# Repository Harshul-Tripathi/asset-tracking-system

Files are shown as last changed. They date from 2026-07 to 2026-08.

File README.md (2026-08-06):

# Anti-Theft Tracking

An industrial project developed in collaboration with **STMicroelectronics** to design and implement a highly accurate, multi-anchor asset tracking and anti-theft system utilizing Ultra-Wideband (UWB) technology that offers centimeter-level precision. 

This repository contains the complete firmware, hardware PCB designs, and comprehensive documentation for the entire project lifecycle.

---
## 👥 Contributors

*   Krishang Singh - Hardware selection, Schematic and Layout design, Low-power optimization
*   Krishna Kumar Mahto - Firmware, Qorvo SDK, Breadboard testing (one way ranging)
*   Harshul Tripathi - MCU Pinout Architecture (CubeMX), AirTag Analysis, System Power Profiling

## 🏗️ System Architecture

The tracking ecosystem relies on a 4-subsystem architecture designed for precise trilateration and efficient power management. The system consists of three stationary anchors and one mobile tag:

### 1. STM32 Anchor (Hub)
*   **Hardware:** NUCLEO-U575ZI-Q + BU03 (UWB Module) + ST67W611M (Wi-Fi Module)
*   **Role:** Acts as the central hub of the tracking system. It interfaces with the tag and the secondary ESP32 anchors to compute the final location of the asset and manage the network. It publishes this data to a dashboard through the ST67W611M Wi-Fi module.
*   **Location:** `firmware/stm32-anchor-hub/nucleo-u575zi-q_bu03/`

### 2. ESP32 Anchors (x2)
*   **Hardware:** ESP32 + UWB Modules
*   **Role:** Two secondary stationary anchors strategically placed to provide the additional reference points required for accurate 2D/3D trilateration. 
*   **Location:** `firmware/esp32-anchors/`

### 3. STM32 Tag
*   **Hardware:** NUCLEO-WBA55CG + BU03 (UWB Module) / Custom Compact PCB
*   **Role:** The mobile asset being tracked. Designed for a compact footprint, it broadcasts its signals to the anchor network.
*   **Location:** `firmware/stm32-tag/Nucleo-WBA55CG_BU03/`

---

## 📂 Repository Structure

The repository is modularized to separate different microcontrollers, hardware designs, and documentation, preventing workspace conflicts.

*   **`/docs`**: Contains all reference materials, component datasheets, project presentations, and research (including AirTag teardowns).
*   **`/firmware`**: Separated source code for the ESP-IDF and STM32CubeIDE workspaces. Each subsystem contains its own build instructions and configurations.
*   **`/hardware`**: Contains the custom compact tag PCB designs (KiCad/Altium). Includes standard EDA source files alongside a `/production` folder for manufacturing Gerbers and BOMs.
  ---

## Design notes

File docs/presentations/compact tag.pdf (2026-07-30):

# Compact Tag w/ STM32WBA55

# -Battery Life Optimization -Communication Modes -Productization Plan

## Current System schematic

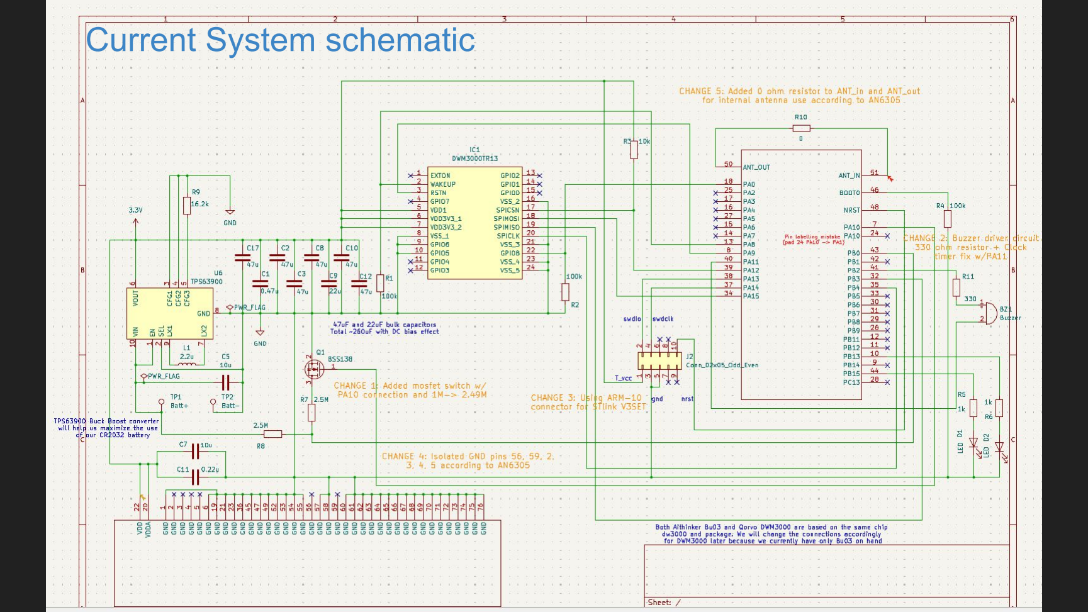
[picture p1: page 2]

# DWM3000 + MLCC Ideal Parameters & Lifespan

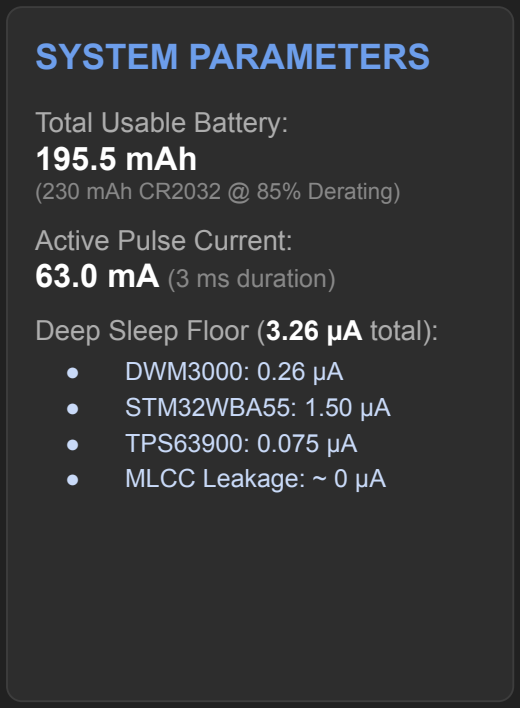
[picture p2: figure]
SYSTEM PARAMETERS; Total Usable Battery: 195.5 mAh; (230 mAh CR2032 @ 85% Derating); Active Pulse Current: 63.0 mA (3 ms duration); Deep Sleep Floor (3.26 µA total):; ● DWM3000: 0.26 µA ● STM32WBA55: 1.50 µA; ● TPS63900: 0.075 µA; ● MLCC Leakage: ~ 0 µA

SCENARIO A: 1 HZ

1 Pulse per Second (86,400/Day)

Active Drain / Day:
3.841 mAh

Sleep Drain / Day:
0.163 mAh

Total Daily Drain:
4.004 mAh/day

ESTIMATED LIFESPAN

# ~48.8 Days

SCENARIO B: 3 HZ

3 Pulses per Second (259,200/Day)

Active Drain / Day:
11.524 mAh

Sleep Drain / Day:
0.162 mAh

Total Daily Drain:
11.686 mAh/day

ESTIMATED LIFESPAN

# ~16.7 Days

# Full tag system Realistic Parameters & Lifespan

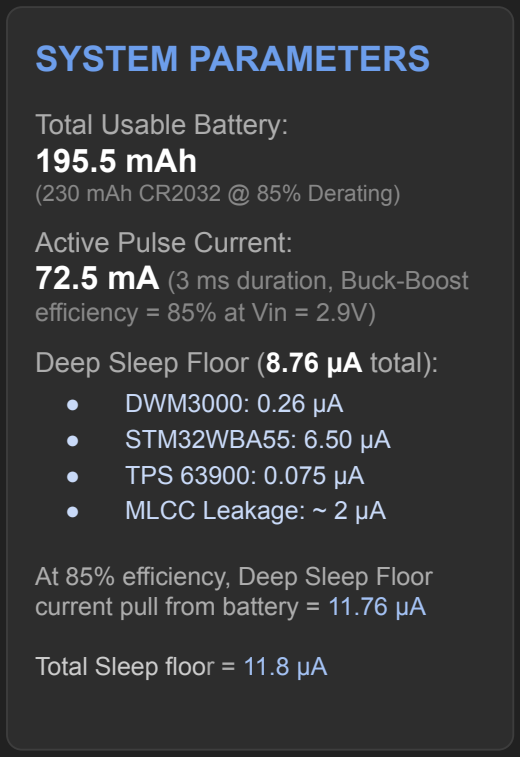
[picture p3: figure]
SYSTEM PARAMETERS; Total Usable Battery: 195.5 mAh; (230 mAh CR2032 @ 85% Derating); Active Pulse Current: 72.5 mA (3 ms duration, Buck-Boost; efficiency = 85% at Vin = 2.9V); Deep Sleep Floor (8.76 µA total):; ● DWM3000: 0.26 µA ● STM32WBA55: 6.50 µA; ● TPS 63900: 0.075 µA ● MLCC Leakage: ~ 2 µA; At 85% efficiency, Deep Sleep Floor current pull from battery = 11.76 µA; Total Sleep floor = 11.8 µA

SCENARIO A: 1 HZ

1 Pulse per Second (86,400/Day)

Active Drain / Day:
5.220 mAh

Sleep Drain / Day:
0.282 mAh

Total Daily Drain:
5.502 mAh/day

ESTIMATED LIFESPAN

# ~35.5 Days

Assuming UWB usage

### 15 mins/ week

# ~13.5 Months

SCENARIO B: 3 HZ

3 Pulses per Second (259,200/Day)

Active Drain / Day:
15.660 mAh

Sleep Drain / Day:
0.281 mAh

Total Daily Drain:
15.941 mAh/day

ESTIMATED LIFESPAN

# ~12.3 Days

Assuming UWB usage

### 15 mins/ week

# ~13 Months

# Apple Airtag Power delivery inspiration

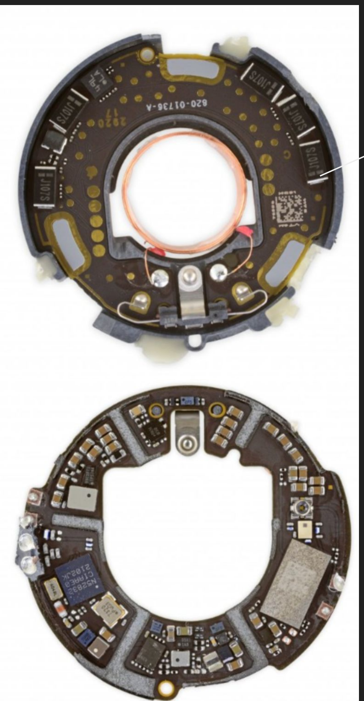
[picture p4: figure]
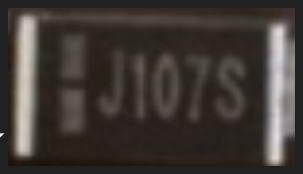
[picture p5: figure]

Capacitance rating (107) : 100 UF Voltage Rating (J) : 6.3V
Tolerance (S) : +50% , -20%
Type : Polymer Tantalum

We can see 5 of these so net total capacitance is around 500 uF

Our system uses following Bulk MLCCs:
6 x 47uF(25V) = 282uF
1 x 22uF(25V) = 22uF
Net Bulk capacitance = 304uF

## The usage of MLCCs allows for no leakage

capacitance and gives us a better UWB lifespan.

# Major Changes Needed for Productization

### Change 1: Integration with BLE(Bluetooth Low Energy) technology

- We utilize the UWB module with another BLE setup (like the one we saw in our visit or
BlueNRG-M2 or STM32WBA5MMG+ANT3216A063R2400A)
- We can use the BLE setup 99% (UWB deep sleep, 142 nA) of the time to conserve battery and get to proximity of the tag without bothering with UWB unless we get close to the tag (<20m) .

### Change 2: Double-Sided Two-Way Ranging (DS-TWR) for UWB communication

Changing our older single-sided ranging system for DS-TWR:

- Stage-1 (Tag Tx , Anchor Rx)- Tag transmits signal for the
initiation of the distance + direction measurement.
- Stage-2 (Tag Rx , Anchor Tx)- Anchor transmits a signal and
also starts counter for ToF then tag receives.
- Stage-3 (Tag Tx , Anchor Rx)- Tag transmits signal while the

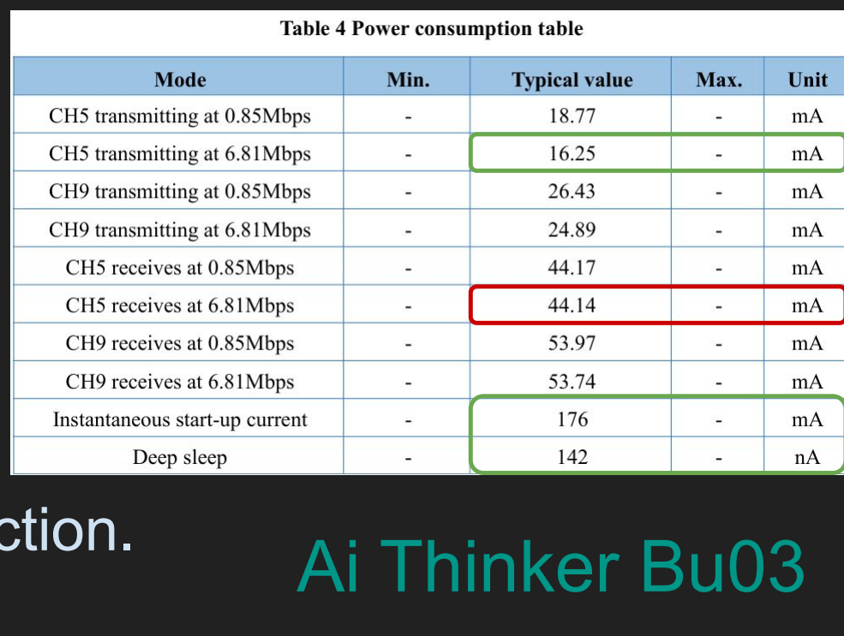
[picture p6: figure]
Ai Thinker Bu03

Anchor receives and stops ToF counter , to find distance + direction.

https://www.st.com/en/wireless-connectivity/bluenrg-m2.html (https://www.st.com/en/wireless-connectivity/bluenrg-m2.html) https://www.digikey.in/en/products/detail/yageo/ANT3216A063R2400A/311-1542-1-ND/3927225 (https://www.digikey.in/en/products/detail/yageo/ANT3216A063R2400A/311-1542-1-ND/3927225)

# Change-1 detailed

- For most of the battery life ,our UWB subsystem will be virtually nonexistent and we will only use BLE technology with Find My app (on iOS w/ UWB support) or Find My Device(by Google,No UWB support).
- Our Tag BLE subsystem will act like a beacon that will broadcast its ID every 2s to every nearby device in its own ecosystem (say iOS) .
- The device will have a GPS location that will upload the Tag ID to Apple cloud which will get picked up by our own Anchor (iPhone) that will give us a rough location as to where our tag is.

~20m

BLE
only

UWB+
minimal
BLE

Anchor(iPhone)

Tag

- Once we get to a reasonable proximity (about 20m), our BLE subsystem will
start using its RSSI indicator to find rough distance between the tag and anchor (accuracy in meters) and when the strength is adequate (around -65 dBm), our MCU will get our UWB subsystem out of Deep-Sleep and into active mode.
- Then we can use our iPhone (with U2/U1 chip) to track the direction and distance to our

DW3000 chip based UWB module/setup without our Change-2 tracking method. Qorvo Nearby Interaction or Apple’s Find My app can handle this part well.

RSSI
starts

# Getting Access to Apple’s Find My

## Apple allows third party devices to enter their iOS ecosystem if they comply with certain guidelines* using the MFi program and have suitable BLE technology in

your circuit.

## A temporary work-around we can use is a masked ID to utilize Apple’s Find My network for BLE purposes and

Qorvo’s nearby interaction for UWB tracking.

## Dw3000 based modules that we plan to use are compliant with IEEE 802.15.4z standard of UWB communication which is also found in UWB subsystems

of higher-end android phones.

*

https://mfi.ap
ple.com/en/h
ow-it-works.ht
ml (https://mfi.apple.com/en/enroll.html)
Portronics World Tag

https://github.com/see
moo-lab/openhaystack (https://github.com/seemoo-lab/openhaystack)

The industry standard method to use UWB communication in unknown terrain is DS-TWR in which we have a 3-signal broadcast (Initialise, Anchor return and Tag return in order)

### 1. Initialize : Tag in Tx mode sends a signal to Anchor to basically

inform the anchor that the tag is reachable for distance calculation, just like t_ready signal sent by slave in AXI.

### 2. Anchor return : Anchor sends the starter signal for

ToF calculation and gets into Rx mode for the Tag return signal.

### 3. Tag return : Tag sends the signal back to anchor to

end the ToF on anchor side and our iPhone anchor is capable of finding the distance and direction from the ToF alone.

# Change-2 detailed

### Anchor

## Tag

Initialise Tag
return

Anchor
return

## TAG

# DS-TWR current pull pattern

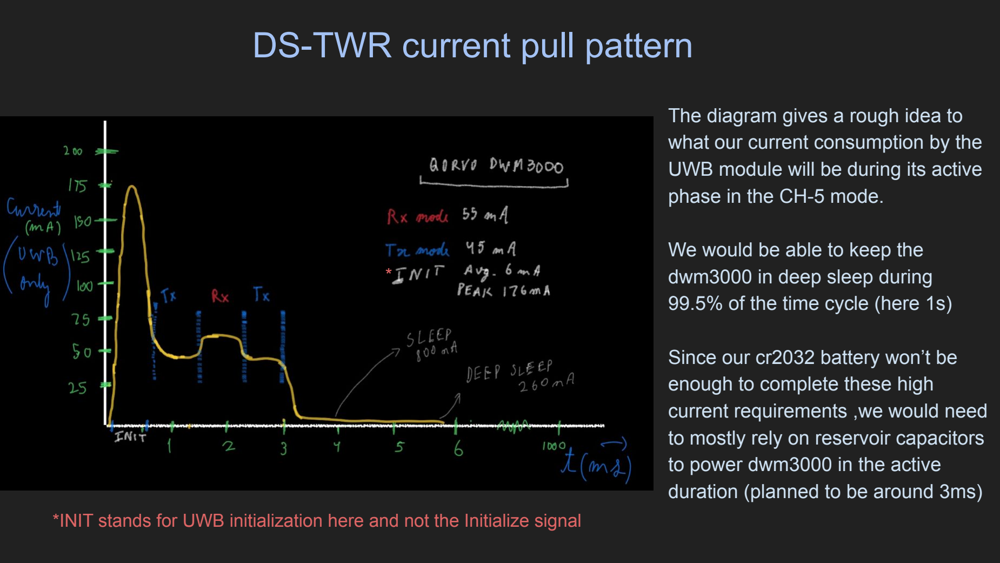
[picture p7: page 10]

The diagram gives a rough idea to what our current consumption by the UWB module will be during its active phase in the CH-5 mode.

We would be able to keep the dwm3000 in deep sleep during 99.5% of the time cycle (here 1s)

Since our cr2032 battery won’t be enough to complete these high current requirements ,we would need to mostly rely on reservoir capacitors to power dwm3000 in the active duration (planned to be around 3ms)

*INIT stands for UWB initialization here and not the Initialize signal

*

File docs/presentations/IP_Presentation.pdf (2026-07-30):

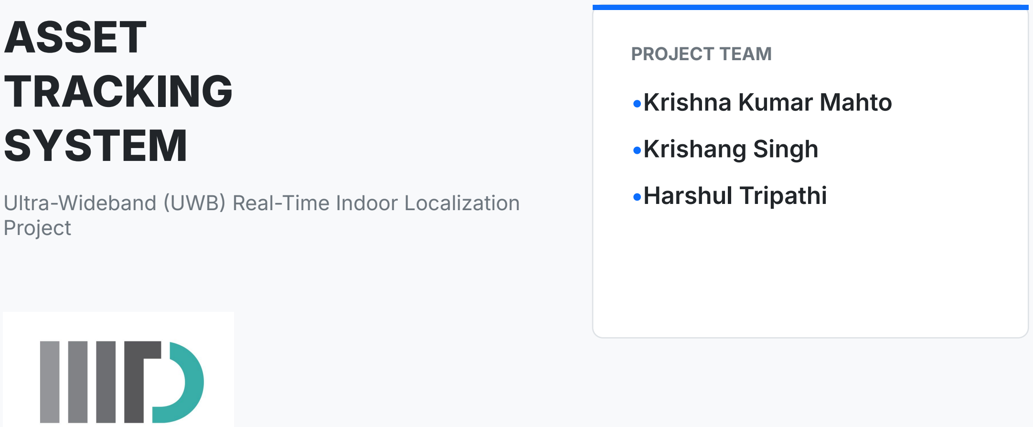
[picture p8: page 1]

# ASSET TRACKING SYSTEM

Ultra-Wideband UWB Real-Time Indoor Localization Project

PROJECT TEAM

### •Krishna Kumar Mahto

### •Krishang Singh

### •Harshul Tripathi

# System Architecture: UWB Tag & Anchor

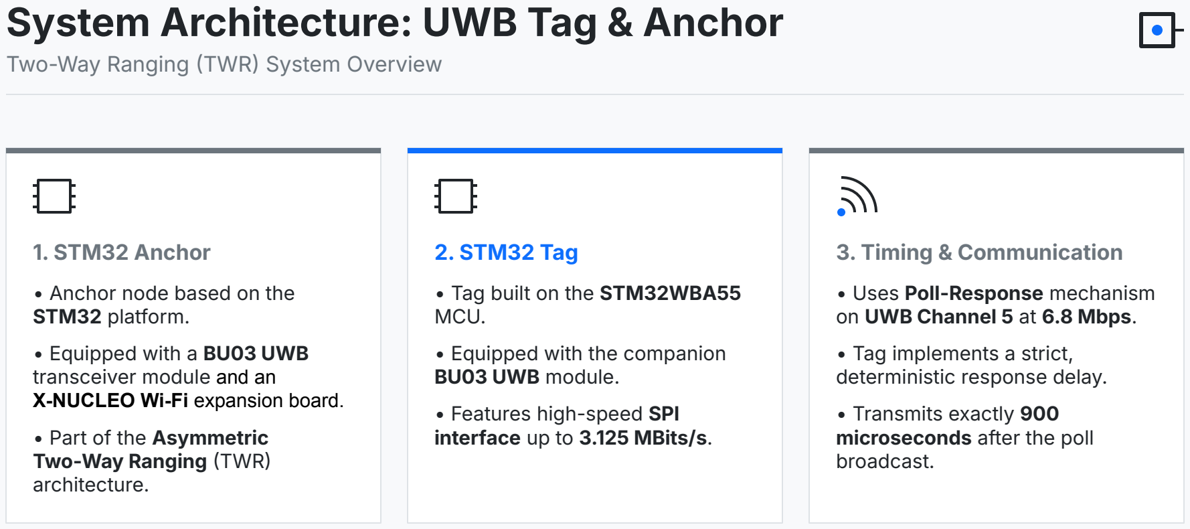
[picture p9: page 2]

Two-Way Ranging TWR System Overview

### 1. STM32 Anchor

- Anchor node based on the STM32 platform.
- Equipped with a BU03 UWB transceiver module and an
X-NUCLEO Wi-Fi expansion board.
- Part of the Asymmetric
Two-Way Ranging TWR
architecture.

### 2. STM32 Tag

- Tag built on the STM32WBA55 MCU.
- Equipped with the companion BU03 UWB module.
- Features high-speed SPI
interface up to 3.125 MBits/s.

### 3. Timing & Communication

- Uses Poll-Response mechanism on UWB Channel 5 at 6.8 Mbps.
- Tag implements a strict, deterministic response delay.
- Transmits exactly 900
microseconds after the poll broadcast.

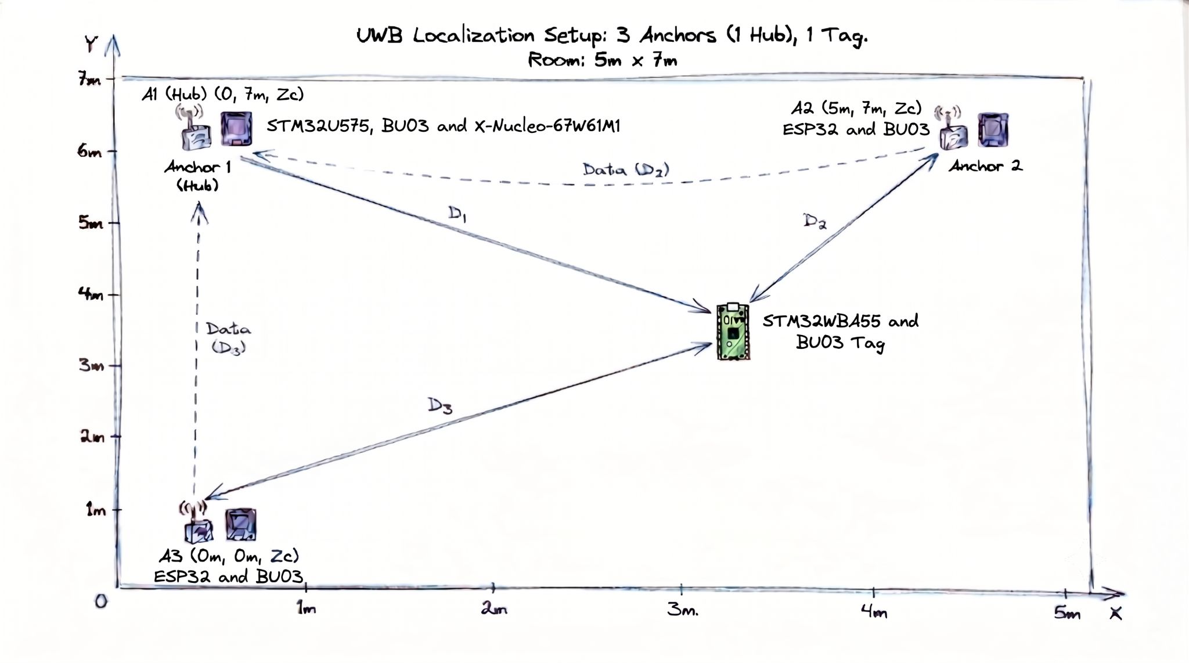
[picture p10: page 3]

# Hardware Specifications

Tag, Anchor, and BU03 Transceiver profiles

TAG NODE HARDWARE

System Platform
STMicroelectronics NUCLEOWBA55CG

MCU: STM32WBA55CGUx
CORE: Cortex-M33 @ 100MHz
OS: Baremetal (No RTOS)
Custom baremetal firmware guarantees nanosecond-level timing precision by eliminating scheduling overhead.

ANCHOR & TRANSCEIVER

Anchor Processing Unit
BOARD: NUCLEO-U575ZI-Q
CORE: STM32U575

Wi-Fi Expansion Profile
BOARD:X-NUCLEO-67W61M1
INTERFACE: Shared SPI1 (via Arduino Uno V3 headers)
Shared UWB Transceiver Profile
MODULE: BU03 Module
TRANSCEIVER: Qorvo / Decawave DW3000 PHY CH / RATE: Channel 5 @ 6.8 Mbps PREAMBLE: 128 Length

# Tag Interfacing & Wiring

STM32WBA BU03

PA15 | MOSI Data Out)
PB3 | MISO Data In)
PB4 | SCK Serial Clock
SPI1 Interface | Control & Debug
PA12 | CS Chip Select
Active Low)
PA11 | RST Hardware Reset)
PB14 | IRQ EXIT 14 Notification)
UART1 | TXPB12 RXPA8

### CRITICAL CONFIGURATION Real-time RX/TX event notifications are handled via the EXTI14

interrupt line on PB14. The debug console operates over UART1 at 115200 baud.

# Anchor Hub Interfacing & Wiring

STM32U5 BU03 & XNUCLEO67W61M1

PB15 | MOSI Data Out)
PB14 | MISO Data In)
PB13 | SCK Serial Clock
SPI2 Interface : BU03 and STM32U5 | Control & Debug
PA4 | CS Chip Select
Active Low)
PB2 | RST Hardware Reset)
PF12 | IRQ EXIT14 Notification)
PF11 | WAKE

### ❖ We are stacking the XNUCLEO67W61M1 Wi-Fi expansion board directly onto the

STM32 Nucleoʼs Arduino Uno V3 connectors to establish a multi-slave SPI1 bus layout.

# Execution Trace & Validation

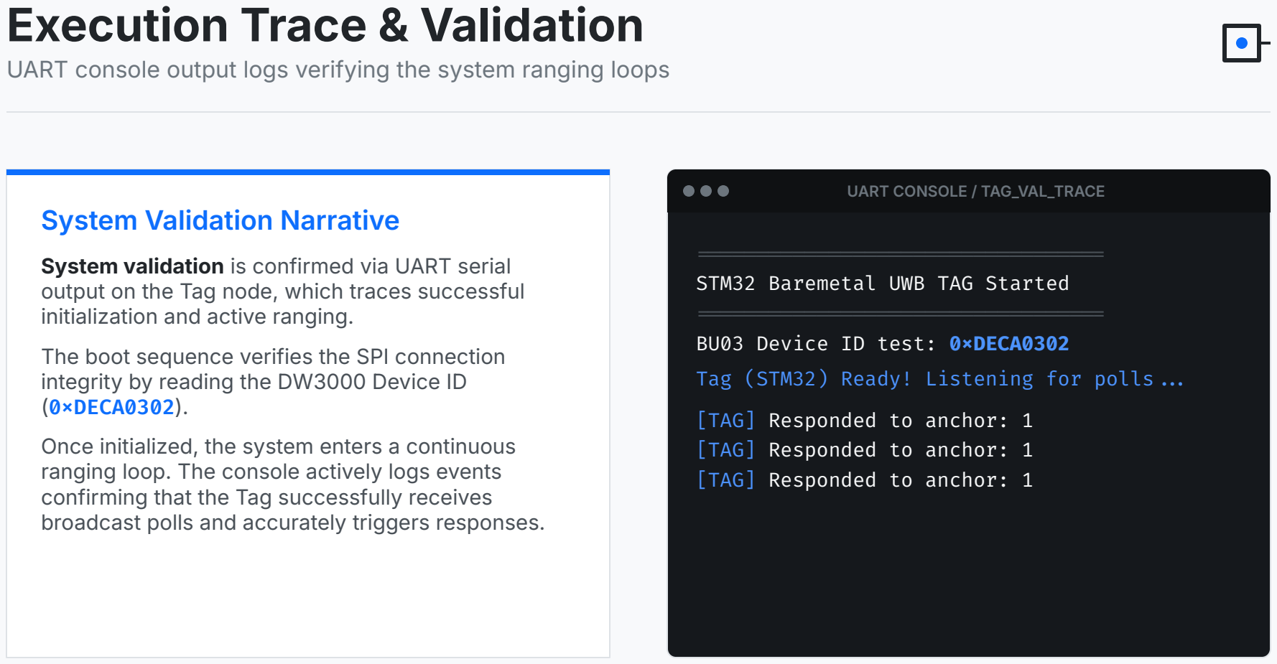
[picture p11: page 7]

UART console output logs verifying the system ranging loops

### System Validation Narrative

System validation is confirmed via UART serial output on the Tag node, which traces successful initialization and active ranging.
The boot sequence verifies the SPI connection integrity by reading the DW3000 Device ID (0xDECA0302).
Once initialized, the system enters a continuous ranging loop. The console actively logs events confirming that the Tag successfully receives broadcast polls and accurately triggers responses.

UART CONSOLE / TAG_VAL_TRACE

================================== STM32 Baremetal UWB TAG Started ==================================
BU03 Device ID test: 0xDECA0302
Tag (STM32) Ready! Listening for polls... [TAG] Responded to anchor: 1
[TAG] Responded to anchor: 1
[TAG] Responded to anchor: 1

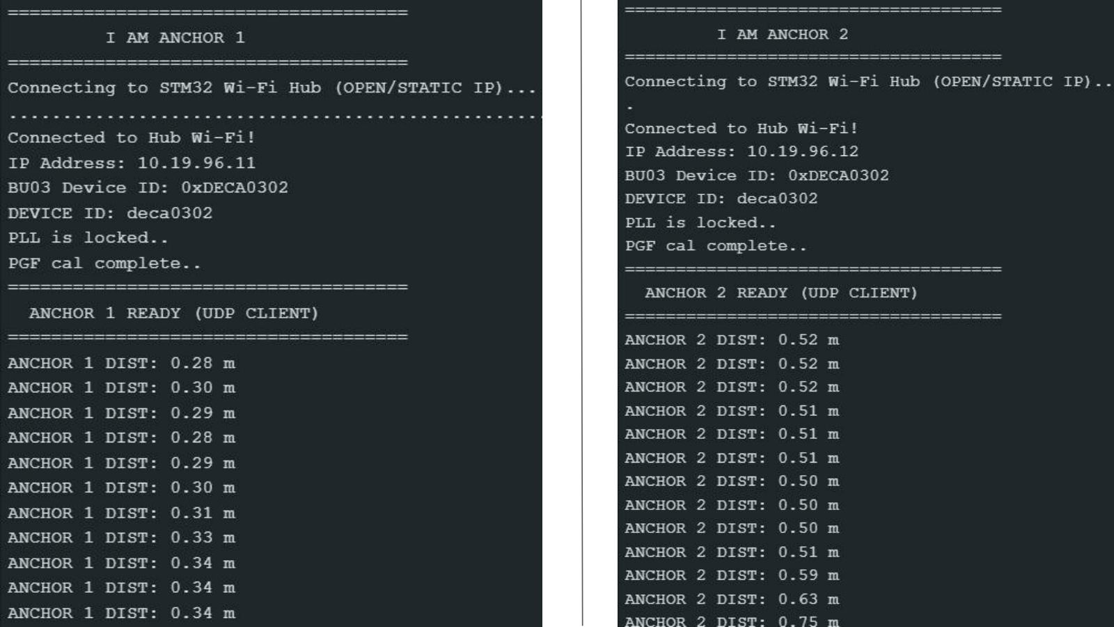
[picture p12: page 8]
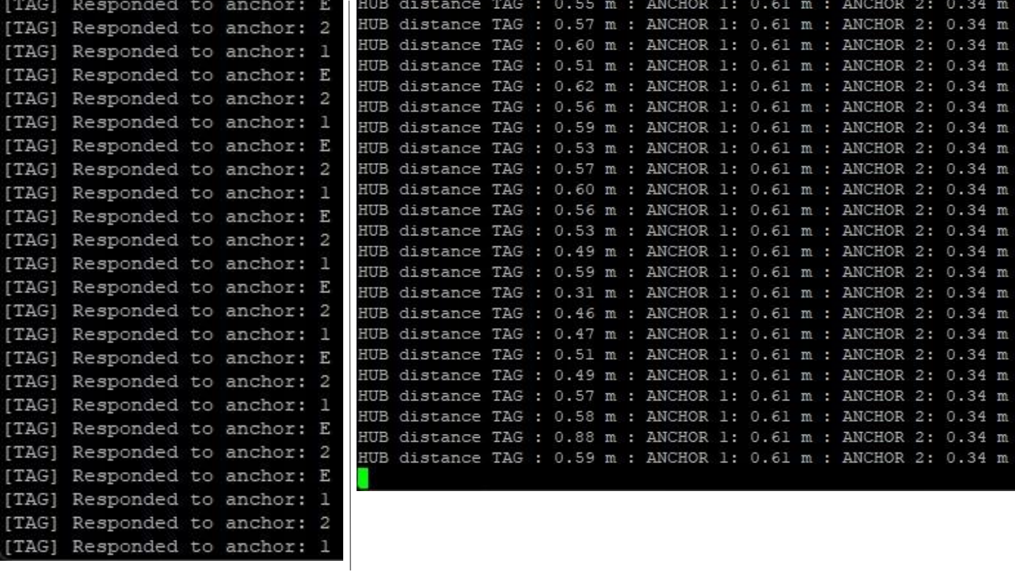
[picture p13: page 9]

### Web-Dashboard

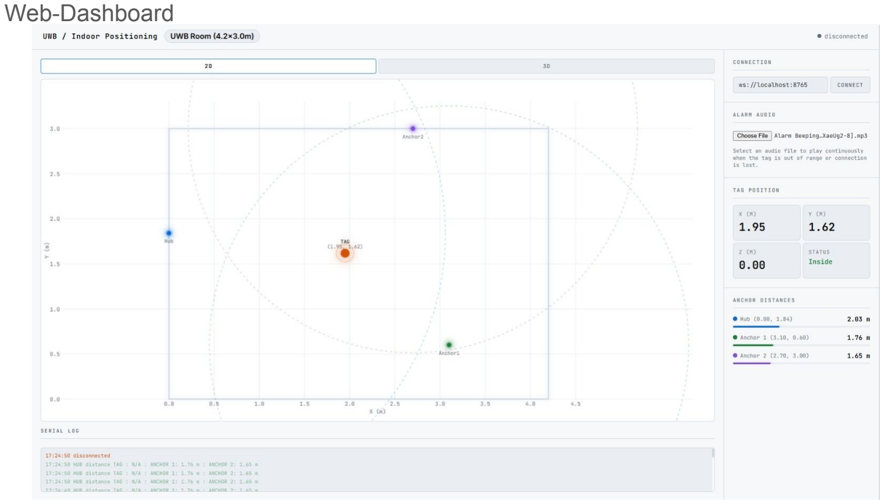
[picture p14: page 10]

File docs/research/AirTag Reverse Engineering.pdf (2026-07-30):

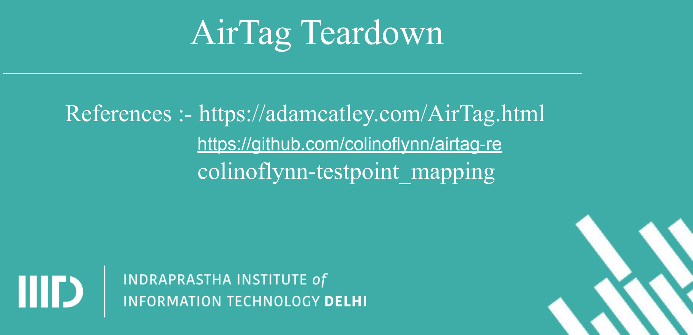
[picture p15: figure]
AirTag Teardown; colinoflynn-testpoint_mapping

# References :- https://adamcatley.com/AirTag.html

# https://github.com/colinoflynn/airtag-re

# Teardown

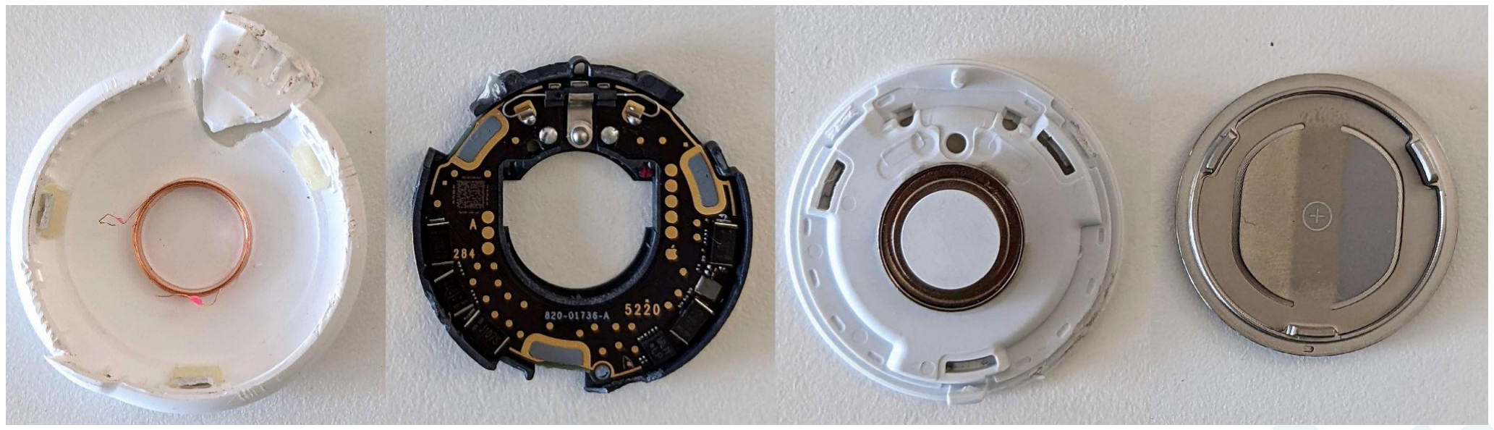
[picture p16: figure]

# Key Findings

### Hardware & Power

- Uses off the shelf components, apart from Apple’s U1 chip for UWB
- The popular nRF52832 is used for BLE and NFC
- Sleep current consumption of 2.3µA gives over 10 years of potential battery life
- nRF needs at least ~1.9V battery voltage to boot up
- 32Mbit flash storage is unencrypted
- nRF programming interface (SWD) easily accessible via test pads and can be unlocked

### Connectivity & Operation

- Updates BLE address and public key once a day at 04:00am
- Updates last byte of advertisement data every 15 minutes
- Transmits BLE advertisement every 2 seconds when away from its owner’s device
- BLE connection interval of 1 second when near its owner’s device

### Lost Mode & Motion

- Goes into a lost mode exactly 3 days after being away from owner
- Makes noise once every 6 hours in lost mode when movement is detected
- Samples accelerometer every 10 seconds when waiting for movement
- Samples accelerometer every 0.5 seconds once motion is detected, for 20 seconds

# PCB Overview

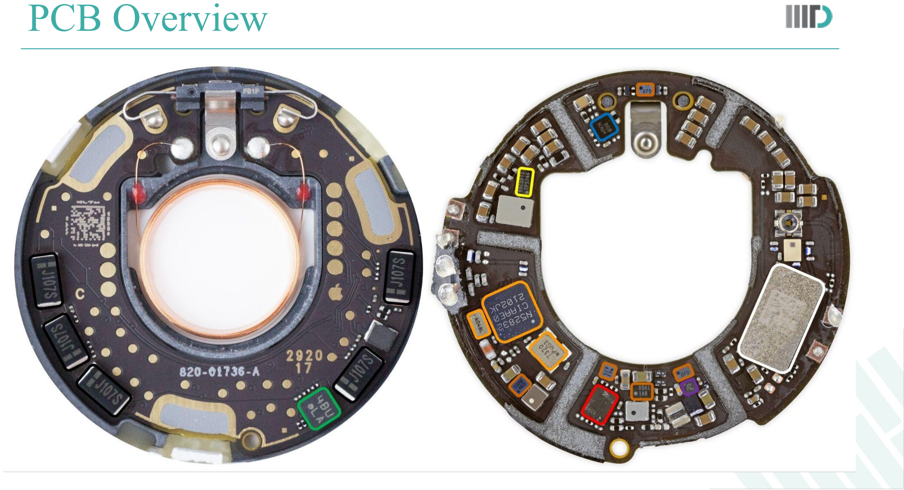
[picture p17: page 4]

# Components used

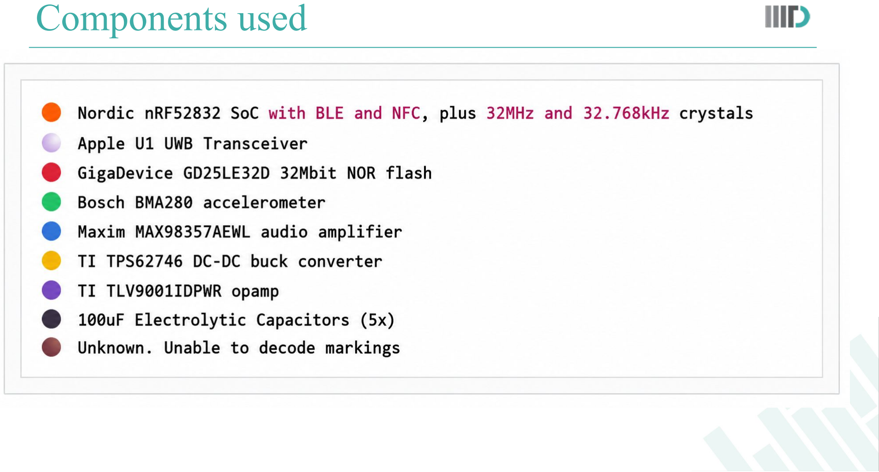
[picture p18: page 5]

# Antennas

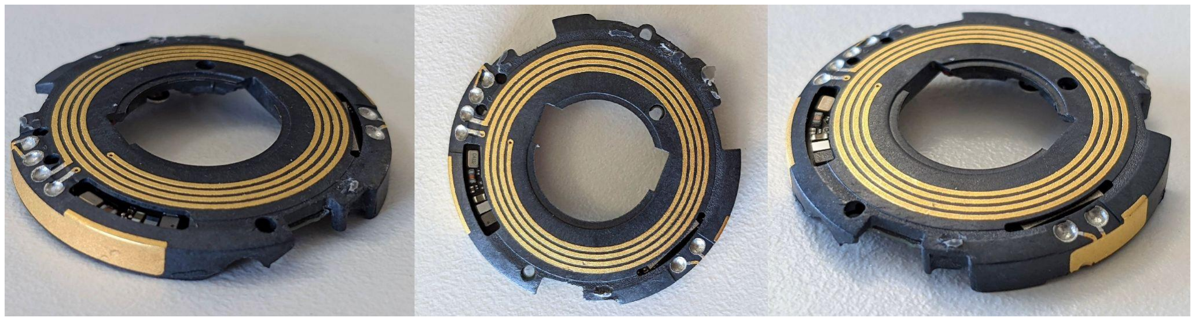
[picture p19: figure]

# 1. Bluetooth Low Energy (left) - 2.4GHz 2. NFC (middle) - 13.56MHz 3. Ultra-Wideband (right) - 6.5-8GHz

# Test Points

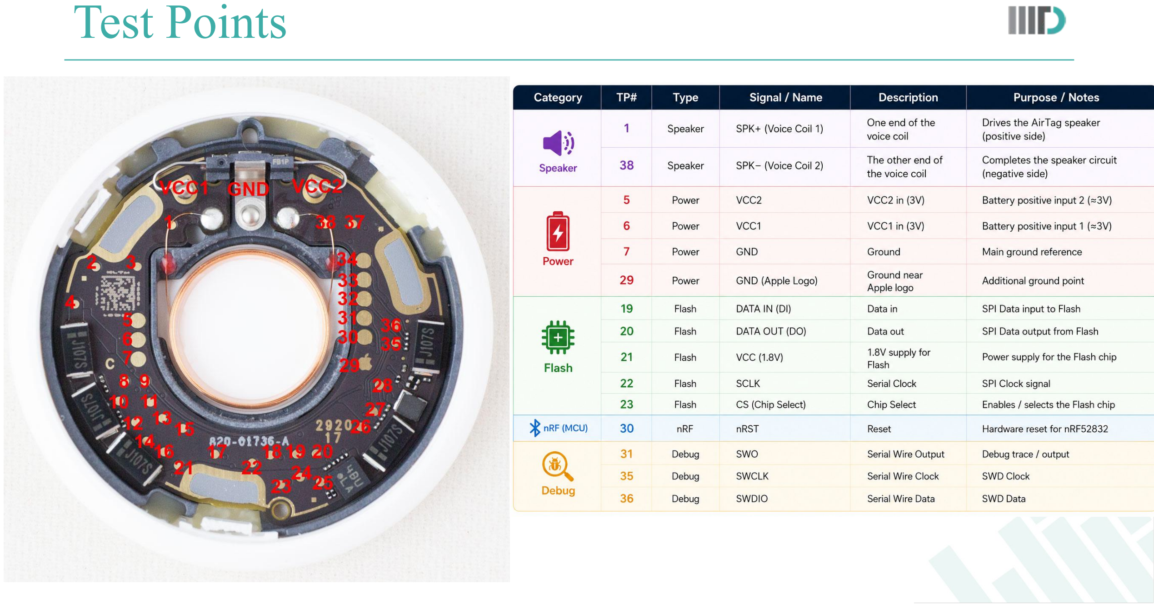
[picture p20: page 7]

# UWB

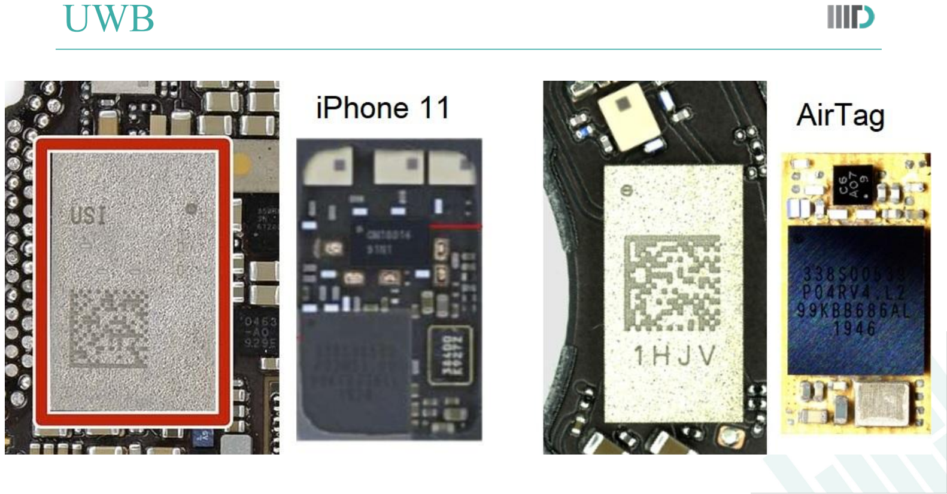
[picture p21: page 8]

# U1 Architecture

- AirTag uses Apple’s U1 Ultra-Wideband chip for precision ranging.
- Operates on UWB Channels 5 (6.5 GHz) and 9 (8 GHz) with 500 MHz bandwidth.
- Uses BPSK modulation and a single UWB antenna.

## - The AirTag primarily performs accurate distance measurement using

Time-of-Flight (ToF).

## - Direction estimation is likely computed by the iPhone using multiple antennas and

spatial processing techniques such as AoA/AoD.

## - This architecture enables compact size, low power consumption, and high ranging

accuracy.

# Higher Resolution Images

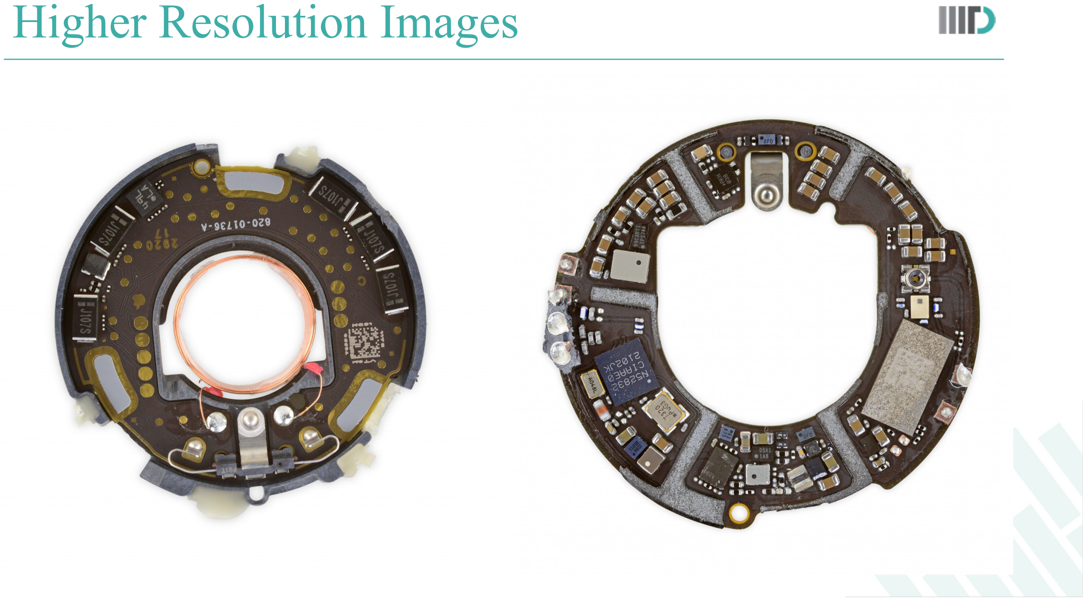
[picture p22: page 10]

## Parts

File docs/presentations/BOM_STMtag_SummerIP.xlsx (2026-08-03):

Item No. | Category | Component Name | Description / Specification | Manufacturer | Manufacturer Part Number (MPN) | Package / Size (in for :) | Quantity | Unit Price(INR) | Total Price | Supplier | Supplier Part Number | Link | Notes
1 | MCU | STM32WBA5MMG module | STM32WBA55 mcu + BL antenna | STMicroelectronics | STM32WBA5MMGH6TR | SIP-LGA76_STM | 1 | - | - | STMicroelectronics | - | nucleo-wba5mmg (https://www.st.com/en/evaluation-tools/nucleo-wba55cg.html)
2 | UWB Module | DWM Module | DWM3000TR13 | Qorvo | DW3110 IC | 24-SMD Module | 1 | 2223.27 | 2223.27 | Digikey | 2312-DWM3000TR13CT-ND - Cut Tape (CT) | dwm3000TR13 (https://www.digikey.in/en/products/detail/qorvo/DWM3000TR13/24367320)
3 | Capacitors(MLCC) | 47uF Cap | 25VDC 47uF | TDK | C3216X5R1E476M160AC | :1206 | 6 | 87.89 | 527.34 | Digikey | 445-8047-1-ND - Cut Tape (CT) | 47uF (https://www.digikey.in/en/products/detail/tdk-corporation/C3216X5R1E476M160AC/2792260)
4 |  | 22uF Cap | 25VDC 22uF | Samsung Electro-Mechanics (https://www.digikey.in/en/supplier-centers/samsung-electro-mechanics-america) | CL21A226MAYNNWE | :0805 | 1 | 28.35 | 28.35 | Digikey | 1276-CL21A226MAYNNWETR-ND - Tape & Reel (TR) | 22uF (https://www.digikey.in/en/products/detail/samsung-electro-mechanics/CL21A226MAYNNWE/16344162)
5 |  | 0.47uF cap | CAP CER 0.47UF 16V X5R 0201 | TAIYO YUDEN | EMK063BBJ474KPLF | :0201 | 1 | 32.13 | 32.13 | Digikey | 587-6264-2-ND - Tape & Reel (TR) | 0.47uF (https://www.digikey.in/en/products/detail/taiyo-yuden/emk063bbj474kplf/9859885)
6 |  | 0.22uF cap | 25VDC 0.22uF | Murata | GRM033R61E224KE01D | :0201 | 1 | 9.45 | 9.45 | Digikey | 490-GRM033R61E224KE01DTR-ND - Tape & Reel (TR) | 0.22uF (https://www.digikey.in/en/products/detail/murata-electronics/grm033r61e224ke01d/10691187)
7 |  | 10uF cap | 25VDC 10uF | Murata | GRM188R61E106KA73D | :0603 | 2 | 24.57 | 49.14 | Digikey | 490-18214-2-ND - Tape & Reel (TR) | 10uF (https://www.digikey.in/en/products/detail/murata-electronics/grm188r61e106ka73d/9867922)
8 | Buck-Boost regulator | TPS63900 | IC REG BUCK BST PROG 400MA 10SON | Texas Instruments | TPS63900DSKR | 10-WFDFN Exposed Pad | 1 | 258.96 | 258.96 | Digikey | 296-TPS63900DSKRTR-ND - Tape & Reel (TR) | TPS63900 (https://www.digikey.in/en/products/detail/texas-instruments/TPS63900DSKR/13535540)
9 | Inductor | 2.2uH , 1.4A | 2.2uH for tps63900 buck boost | TAIYO YUDEN | LSCND1608HKT2R2MF | :0603 | 1 | 24.57 | 24.57 | Digikey | 587-LSCND1608HKT2R2MFTR-ND - Tape & Reel (TR) | 2.2uH (https://www.digikey.in/en/products/detail/taiyo-yuden/LSCND1608HKT2R2MF/22576654)
10 | Resistor | 10 kohm , 0.33W | Needed for pull up resistors | Vishay Dale | RCS040210K0JNED | :0402 | 1 | 12.29 | 12.29 | Digikey | 541-2916-2-ND - Tape & Reel (TR) | 10k (https://www.digikey.in/en/products/detail/vishay-dale/RCS040210K0JNED/5867062)
 |  | 100kohm, 0.1W | for pull down resistors | panasonic | ERJ-2RKF1003X | :0402 | 3 | 9.45 | 28.35 | Digikey | P100KLTR-ND - Tape & Reel (TR) | 100k (https://www.digikey.in/en/products/detail/panasonic-industry/ERJ-2RKF1003X/192081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)
 |  | 1kohm, 0.1W | LED protection | panasonic | ERJ-2RKF1001X | :0402 | 2 | 9.45 | 18.9 | Digikey | P1.00KLTR-ND - Tape & Reel (TR) | 1k (https://www.digikey.in/en/products/detail/panasonic-industry/ERJ-2RKF1001X/79729)
 |  | 2.49 Mohm, 0.1W | Battery monitor ADC | KOA-Speer | RK73H1ETTP2494F | :0402 | 2 | 9.45 | 18.9 | Digikey | 2019-RK73H1ETTP2494FTR-ND | 2.5M (https://www.digikey.in/en/products/detail/koa-speer-electronics-inc/RK73H1ETTP2494F/9844658)
 |  | 16.2kohm | TPS63900 config3 | Vishay Dale | CRCW040216K2FKEDHP | :0402 | 1 | 9.45 | 9.45 | Digikey | 541-CRCW040216K2FKEDHPTR-ND | 16.2k (https://www.digikey.in/en/products/detail/vishay-dale/CRCW040216K2FKEDHP/2225501)
 |  | 330 ohm | MCU protection, piezo buzzer | Vishay Dale | CRCW0402330RJNEDHP | :0402 | 1 |  |  | Digikey | 541-CRCW0402330RJNEDHPTR-ND | 330ohm (https://www.digikey.in/en/products/detail/vishay-dale/CRCW0402330RJNEDHP/2225772)
 |  | 0 ohm | RES 0 OHM JUMPER 1/3W | Vishay Dale | RCS04020000Z0ED | :0402 | 2 |  |  | Digikey | RCS04020000Z0ED | 0 ohm (https://www.digikey.in/en/products/detail/vishay-dale/RCS04020000Z0ED/5867023)
11 | LED | Vf = 1.9V | Green LED 574nm 1.9V | QT Brightek (QTB) | QBLP595-AG15-2897 | :0402 | 2 | 22.68 | 45.36 | Digikey | 1516-QBLP595-AG15-2897TR-ND - Tape & Reel (TR) | LED (https://www.digikey.in/en/products/detail/qt-brightek-qtb/QBLP595-AG15-2897/17049386)
12 | Buzzer | 74dB, supply 6mA | BUZZER PIEZO 1~25V 7.5X7.5 SMD | Mallory Sonalert Products Inc. | AST0760MCTRQ | 7.5x7.5mm | 1 | 225.88 | 225.88 | Digikey | 458-AST0760MCTRQTR-ND - Tape & Reel (TR) | Buzzer (https://www.digikey.in/en/products/detail/mallory-sonalert-products-inc/AST0760MCTRQ/11567566)
13 | n-Mosfet | BSS138, 0.22A, 50V | Battery monitor switch. N-Channel 50 V 220mA (Tj) 430mW Surface Mount SOT-23 | Good-Ark Semiconductor | BSS138 | SOT-23 | 1 |  |  |  | 4786-BSS138TR-ND | mosfet (https://www.digikey.in/en/products/detail/good-ark-semiconductor/BSS138/18667774)
 |  |  |  |  |  |  |  | Grand Total | 3512.34
 |  |  |  |  |  |  |  | (with taxes)
 | EXTRA ITEMS
13 | AiThinker BU04 | Double Antenna UWB tarnsceiver | Full Kit | Aithinker |  | SMD-34 compatible with DIP-16 |  |  |  |  |  | Bu04- Alibaba.com (https://www.alibaba.com/product-detail/Ai-Thinker-UWB-indoor-bidirectional-ranging_1601270808519.html) | Bu04- Robu.in (https://robu.in/product/ai-thinker-bu04-kit-ultra-uwb-development-board/)
14 | ST67W611M1 | Wireless Connectivity Module | Wifi + BLE Coprocessor | STMicroelectronics | ST67W611M1A6BTR | 12.28 * 17.28 * 2.4 mm | 1 | - | - | STMicroelectronics | - | st67w611m1 (https://www.st.com/en/wireless-connectivity/st67w611m1.html)
5 |  | 4.7uF cap | 25VDC 4.7uF | Murata | GRM155C61E475ME15J | :0402 | 1
9 | Crystal oscillator | crystal | oscillator crystal 32MHz | Murata | XRCGE32M000FBA1AR0 | :0806 | 1 | 37 | 37 | Mouser | 520-ECS32761210B2NTR | crystal (https://www.mouser.in/ProductDetail/Murata-Electronics/XRCGE32M000FBA1AR0?qs=wT7LY0lnAe3g8bsvlH9OVQ%3D%3D)
10 |  | Oscillator capacitor | 25V 8pF | Murata | 490-GRM0335C1E8R0BA01DTR-ND | :0201 | 2 | 9.3 |  |  |  | 6pF (https://www.digikey.in/en/products/detail/murata-electronics/GRM0335C1E8R0BA01D/4358659)
6 |  | 2.2uF cap | CAP CER 2.2UF 16V X5R 0402 | Murata | GRM035R61C225ME01D | :0402 | 1 | 15.12 | 15.12 | Digikey | 490-10695-1-ND - Cut Tape (CT) | 2.2 uF (https://www.digikey.in/en/products/detail/murata-electronics/GRM155R61C225KE11D/4905134)

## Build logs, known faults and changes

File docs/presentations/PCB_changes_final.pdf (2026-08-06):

### CHANGES made after technical discussion on 3rd July, 2026

**All BOM changes have been highlighted in yellow

CHANGE 1: Added BSS138 n-type MOSFET to be used as a switch to break the connection for battery monitoring, with gate of BSS138 connected to PA10 (GPIO output mode)
We can configure the BSS138 to turn the switch on and off whenever needed

CHANGE 2: Buzzer driver circuit installed by adding a protection 330ohm resistor in series to the buzzer circuit in series and matched the clock channel on both driving pins of buzzer to be PA11(TIM1_CH1) and PB2 (TIM1_CH1N)

CHANGE 3: Using ARM-10 connector included in the STlink V3SET as i couldn’t fit the STDC14 version on the board due to physical and mapping constraints

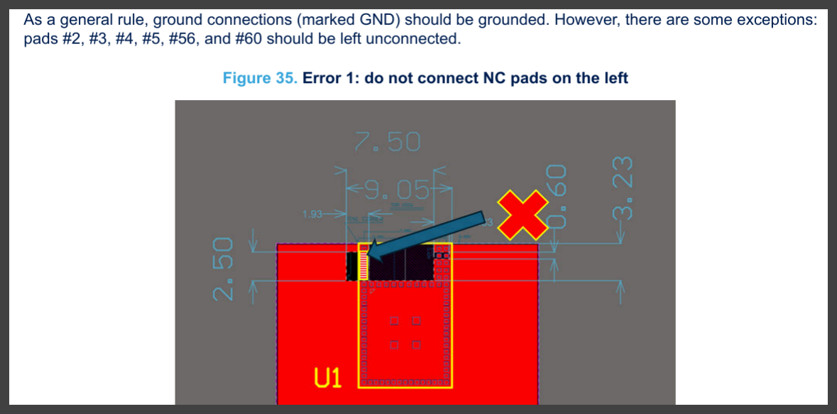
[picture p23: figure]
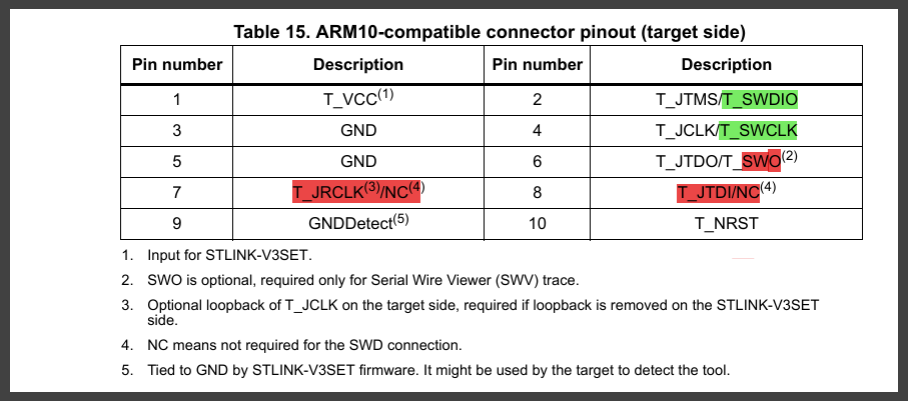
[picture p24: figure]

CHANGE 4: Followed AN6305 to leave pins 2, 3, 4, 5, 56 and 59 ungrounded and isolated and created a no power and signal plane ruled zone (Back copper [MCU layer] , ln2 [3.3V power plane] and ln1 [GND power plane]) under the desired placement as given in the above circuit.

CHANGE 5: Added 0 ohm resistor between ANT_in and ANT_out to use the internal antenna

BOM is updated at BOM_changed (https://docs.google.com/spreadsheets/d/1hblhsTxwv2oZ0Glx2I5-RgQRU_NxM7c-/edit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)

I have also updated the PCB constraints to match those on the website of PCBpower with 0 critical errors found on the board.

I have also marked all of the above changes on the schematic.

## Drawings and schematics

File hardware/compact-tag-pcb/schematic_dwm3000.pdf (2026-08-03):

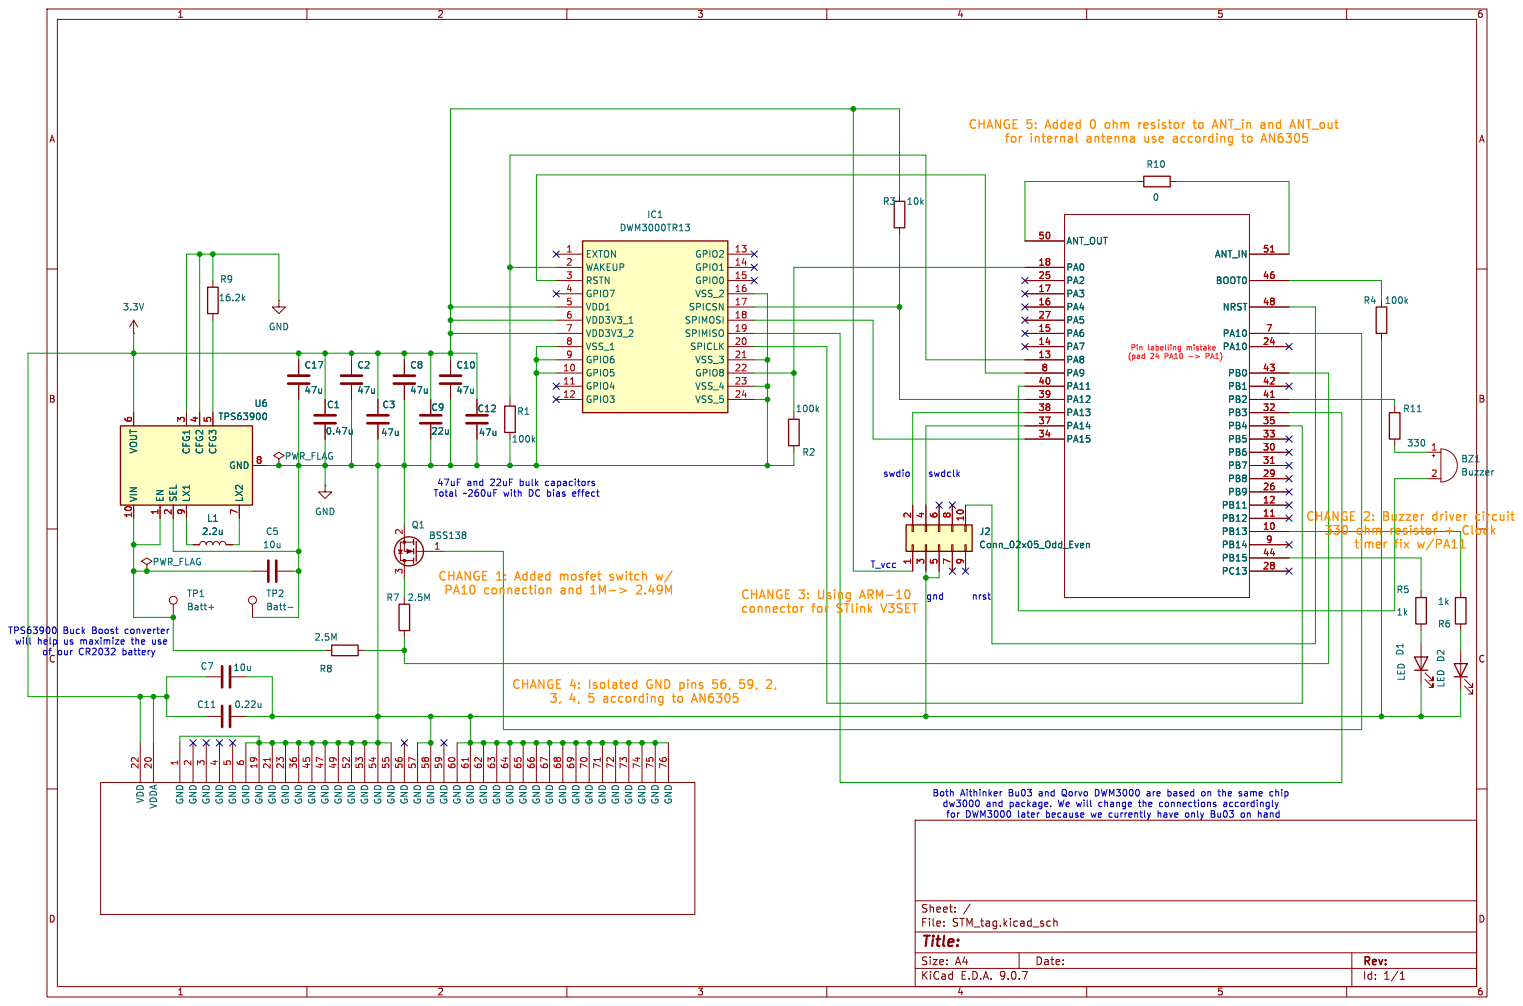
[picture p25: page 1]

for internal antenna use according to AN6305

6 GND 19 GND 21 GND 23 GND 36 GND 45 GND 47 GND 49 GND 52 GND 53 GND 54 GND 55 GND 56 GND 57 GND 58 GND 59 GND 60 GND 61 GND 62 GND 63 GND 64 GND 65 GND 66 GND 67 GND 68 GND 69 GND 70 GND 71 GND 72 GND 73 GND 74 GND 75 GND 76 R9

swdclk 47uF and 22uF bulk capacitors Total ~260uF with DC bias effect L1

CHANGE 2: Buzzer driver circuit
330 ohm resistor + Clock
timer fix w/PA11

CHANGE 1: Added mosfet switch w/

CHANGE 4: Isolated GND pins 56, 59, 2,
3, 4, 5 according to AN6305

Id: 1/1 Title: File: STM_tag.kicad_sch Sheet: /

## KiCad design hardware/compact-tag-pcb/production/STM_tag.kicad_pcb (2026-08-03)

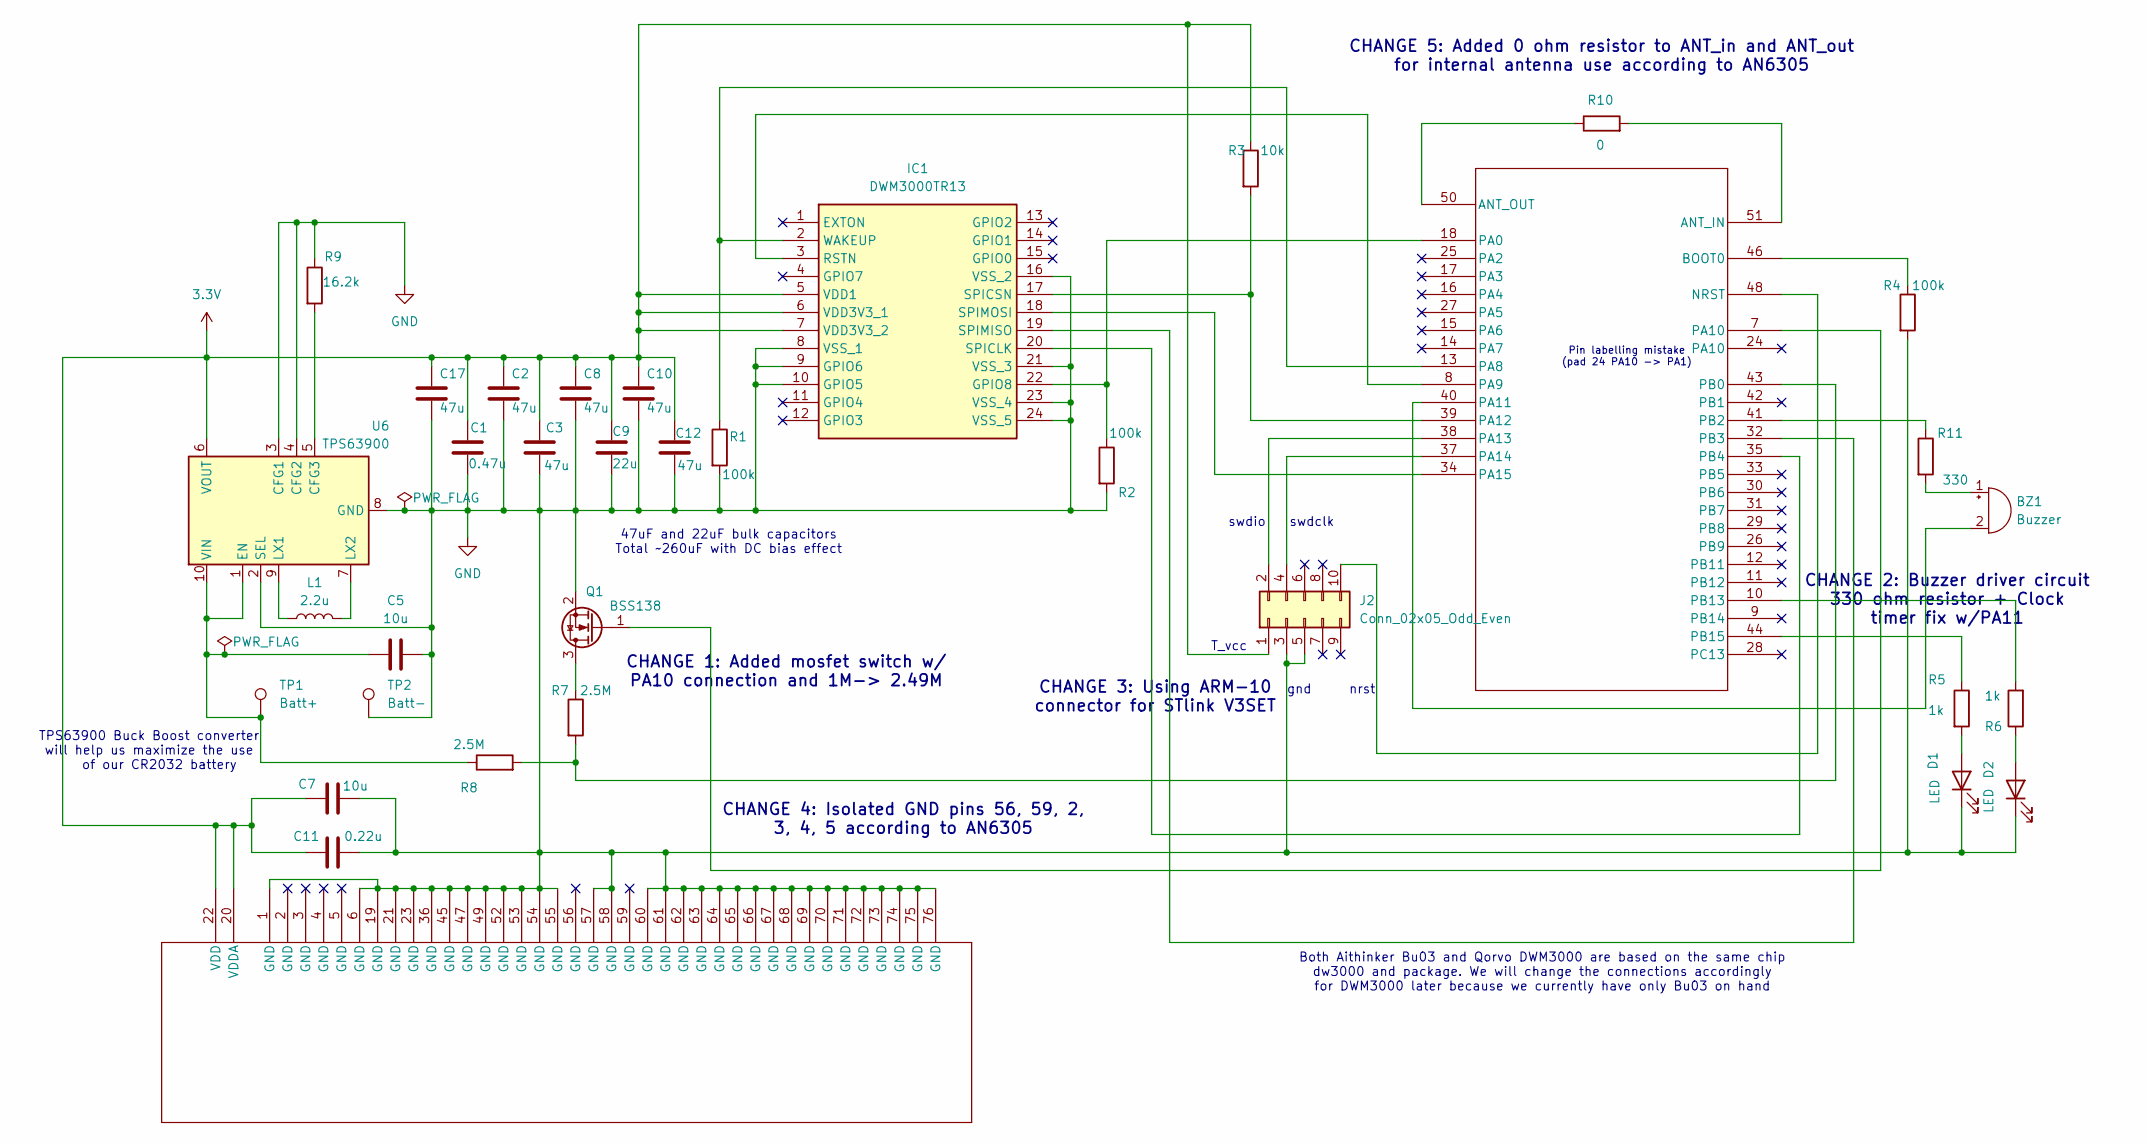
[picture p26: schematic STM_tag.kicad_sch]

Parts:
BZ1: Buzzer; AST0760_MAL
C1: 0.47u; C_0402_1005Metric
C2, C3, C8, C10, C12, C17: 47u; C_1206_3216Metric
C5, C7: 10u; C_0603_1608Metric
C9: 22u; C_0805_2012Metric
C11: 0.22u; C_0402_1005Metric
D1, D2: LED; LED_0402_1005Metric
IC1: DWM3000TR13; Manufacturer_Part_Number DWM3000TR13; Mouser Part Number 772-DWM3000TR13
J2: Conn_02x05_Odd_Even; PinHeader_2x05_P1.27mm_Vertical_SMD
L1: 2.2u; L_0603_1608Metric
Q1: BSS138; SOT-23
R1, R2, R4: 100k; R_0402_1005Metric
R3: 10k; R_0402_1005Metric
R5, R6: 1k; R_0402_1005Metric
R7, R8: 2.5M; R_0402_1005Metric
R9: 16.2k; R_0402_1005Metric
R10: 0; R_0402_1005Metric
R11: 330; R_0402_1005Metric
TP1: Batt+; TestPoint_THTPad_1.0x1.0mm_Drill0.5mm
TP2: Batt-; TestPoint_THTPad_1.0x1.0mm_Drill0.5mm
U3: STM32WBA5MMGH6TR; SIP-LGA76_STM
U6: TPS63900; WSON-10-1EP_2.5x2.5mm_P0.5mm_EP1.2x2mm_ThermalVias

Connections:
3.3V: C1.1, C2.1, C3.1, C7.1, C8.1, C9.1, C10.1, C11.1, C12.1, C17.1, IC1.5 (VDD1), IC1.6 (VDD3V3_1), IC1.7 (VDD3V3_2), J2.1, R3.1, U3.20 (VDDA), U3.22 (VDD), U6.6 (VOUT)
GND: C1.2, C2.2, C3.2, C5.2, C7.2, C8.2, C9.2, C10.2, C11.2, C12.2, C17.2, D1.1 (K), D2.1 (K), IC1.8 (VSS_1), IC1.9 (GPIO6), IC1.10 (GPIO5), IC1.16 (VSS_2), IC1.21 (VSS_3), IC1.23 (VSS_4), IC1.24 (VSS_5), J2.3, J2.5, Q1.2 (S), R1.2, R2.2, R4.2, R9.1, TP2.1, U3.1 (GND), U3.6 (GND), U3.19 (GND), U3.21 (GND), U3.23 (GND), U3.36 (GND), U3.45 (GND), U3.47 (GND), U3.49 (GND), U3.52 (GND), U3.53 (GND), U3.54 (GND), U3.55 (GND), U3.57 (GND), U3.58 (GND), U3.60 (GND), U3.61 (GND), U3.62 (GND), U3.63 (GND), U3.64 (GND), U3.65 (GND), U3.66 (GND), U3.67 (GND), U3.68 (GND), U3.69 (GND), U3.70 (GND), U3.71 (GND), U3.72 (GND), U3.73 (GND), U3.74 (GND), U3.75 (GND), U3.76 (GND), U6.2 (SEL), U6.3 (CFG1), U6.4 (CFG2), U6.8 (GND), U6.11 (GND)
unnamed: BZ1.1 (+), R11.2
unnamed: BZ1.2 (-), U3.40 (PA11)
unnamed: D1.2 (A), R5.2
unnamed: D2.2 (A), R6.1
unnamed: IC1.22 (GPIO8), R2.1, U3.18 (PA0)
unnamed: IC1.3 (RSTN), U3.8 (PA9)
unnamed: IC1.20 (SPICLK), U3.35 (PB4)
unnamed: IC1.17 (SPICSN), R3.2, U3.39 (PA12)
unnamed: IC1.19 (SPIMISO), U3.32 (PB3)
unnamed: IC1.18 (SPIMOSI), U3.34 (PA15)
unnamed: IC1.2 (WAKEUP), R1.1, U3.13 (PA8)
unnamed: J2.2, U3.38 (PA13)
unnamed: J2.4, U3.37 (PA14)
unnamed: J2.10, U3.48 (NRST)
unnamed: Q1.3 (D), R7.1
unnamed: Q1.1 (G), U3.7 (PA10)
unnamed: R10.2, U3.51 (ANT_IN)
unnamed: R10.1, U3.50 (ANT_OUT)
unnamed: R4.1, U3.46 (BOOT0)
unnamed: R7.2, R8.2, U3.43 (PB0)
unnamed: R11.1, U3.41 (PB2)
unnamed: R6.2, U3.10 (PB13)
unnamed: R5.1, U3.44 (PB15)
unnamed: R9.2, U6.5 (CFG3)
unnamed: C5.1, R8.1, TP1.1, U6.1 (EN), U6.10 (VIN)
unnamed: L1.1, U6.9 (LX1)
unnamed: L1.2, U6.7 (LX2)

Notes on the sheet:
swdclk
CHANGE 4: Isolated GND pins 56, 59, 2, 3, 4, 5 according to AN6305
47uF and 22uF bulk capacitors Total ~260uF with DC bias effect
CHANGE 2: Buzzer driver circuit 330 ohm resistor + Clock timer fix w/PA11
Pin labelling mistake (pad 24 PA10 -> PA1)
CHANGE 3: Using ARM-10 connector for STlink V3SET
CHANGE 1: Added mosfet switch w/ PA10 connection and 1M-> 2.49M
gnd
TPS63900 Buck Boost converter will help us maximize the use of our CR2032 battery
nrst
CHANGE 5: Added 0 ohm resistor to ANT_in and ANT_out for internal antenna use according to AN6305
swdio
T_vcc
Both Aithinker Bu03 and Qorvo DWM3000 are based on the same chip dw3000 and package. We will change the connections accordingly for DWM3000 later because we currently have only Bu03 on hand

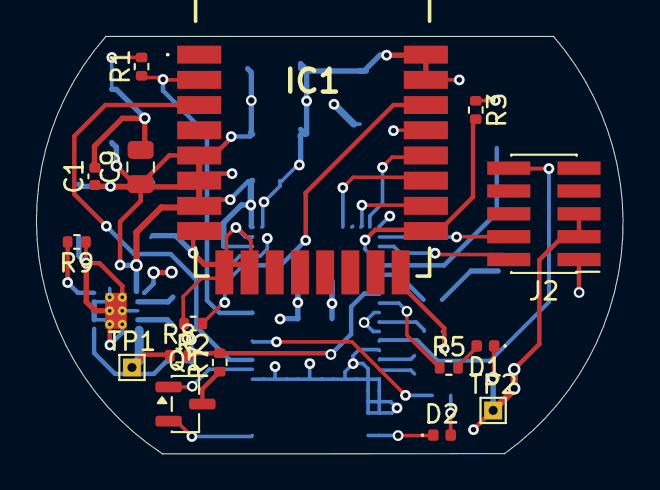
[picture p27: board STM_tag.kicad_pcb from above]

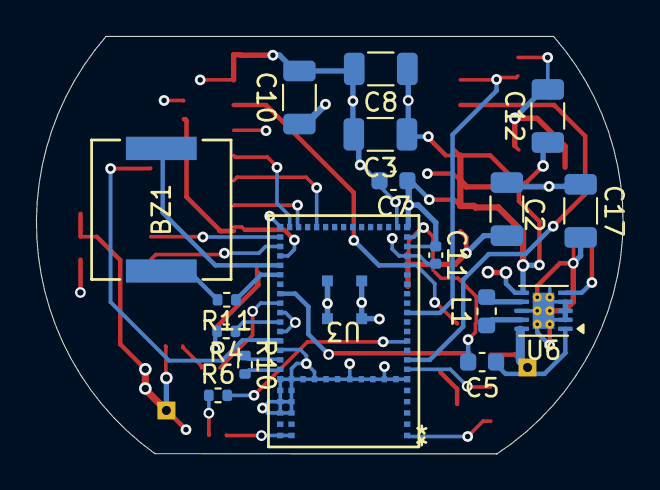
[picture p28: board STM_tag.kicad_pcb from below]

Board: 4 copper layers, 32.6 x 23.2 mm, 33 parts (17 on the bottom side), 29 nets.

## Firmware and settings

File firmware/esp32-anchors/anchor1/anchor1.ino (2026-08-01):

/*
 * UWB Anchor 1 - UDP to STM32 Hub
 */
#include <SPI.h>
#include "dw3000.h"
#include "soc/soc.h"
#include "soc/rtc_cntl_reg.h"
#include <WiFi.h>
#include <WiFiUdp.h>

#define PIN_RST 27
#define PIN_IRQ 34
#define PIN_SS  5

#define RNG_DELAY_MS                500  // Delay between pings
#define TX_ANT_DLY                  16385
#define RX_ANT_DLY                  16385
#define ALL_MSG_COMMON_LEN          10
#define ALL_MSG_SN_IDX              2
#define RESP_MSG_POLL_RX_TS_IDX     10
#define RESP_MSG_RESP_TX_TS_IDX     14
#define POLL_TX_TO_RESP_RX_DLY_UUS  300
#define RESP_RX_TIMEOUT_UUS         3000

// Filter settings
#define FILTER_SIZE     5
#define MAX_JUMP_M      0.5
#define MAX_VALID_M     20.0

const char* ssid = "UWB_HUB";
const char* password = "12345678";

WiFiUDP udp;
const int udpPort = 5000;

static dwt_config_t config = {
    5, DWT_PLEN_128, DWT_PAC8, 9, 9, 1,
    DWT_BR_6M8, DWT_PHRMODE_STD, DWT_PHRRATE_STD,
    (129 + 8 - 8), DWT_STS_MODE_OFF, DWT_STS_LEN_64, DWT_PDOA_M0
};

static uint8_t tx_poll_msg[] = {0x41, 0x88, 0, 0xCA, 0xDE, 'W','A','V','1', 0xE0, 0, 0};
static uint8_t rx_resp_msg[] = {0x41, 0x88, 0, 0xCA, 0xDE, 'V','E','W','1', 0xE1, 0,0,0,0,0,0,0,0,0,0};

static uint8_t frame_seq_nb = 0;
static uint8_t rx_buffer[20];
static uint32_t status_reg = 0;
static double distance = 0;

// Filter state
static double dist_history[FILTER_SIZE] = {0};
static int hist_idx    = 0;
static int hist_filled = 0;
static double last_valid = -1.0;

extern dwt_txconfig_t txconfig_options;

int reject_count  = 0;

// Returns filtered distance, or -1 if rejected
double applyFilter(double raw) {
    if (raw <= 0 || raw > MAX_VALID_M) {
        reject_count++;
        return -1.0;
    }
    if (last_valid > 0 && fabs(raw - last_valid) > MAX_JUMP_M) {
        reject_count++;
        return -1.0;
    }
    last_valid = raw;

    dist_history[hist_idx] = raw;
    hist_idx = (hist_idx + 1) % FILTER_SIZE;
    if (hist_filled < FILTER_SIZE) hist_filled++;

    double sum = 0;
    for (int i = 0; i < hist_filled; i++) sum += dist_history[i];
    return sum / hist_filled;
}

void setup() {
    WRITE_PERI_REG(RTC_CNTL_BROWN_OUT_REG, 0);  // disable brownout
    Serial.begin(115200);
    delay(1000);

    Serial.println("=====================================");
    Serial.println("         I AM ANCHOR 1");
    Serial.println("=====================================");

    Serial.println("Connecting to STM32 Wi-Fi Hub (OPEN/STATIC IP)...");
    
    // Erase old credentials in case it's trying to use the old password
    WiFi.disconnect(true, true); 
    delay(100);
    
    WiFi.mode(WIFI_STA);
    
    IPAddress local_IP(10, 19, 96, 11);
    IPAddress gateway(10, 19, 96, 1);
    IPAddress subnet(255, 255, 255, 0);
    WiFi.config(local_IP, gateway, subnet);
    
    WiFi.begin(ssid, password);
    while (WiFi.status() != WL_CONNECTED) {
        delay(500);
        Serial.print(".");
    }
    Serial.println("\nConnected to Hub Wi-Fi!");
    Serial.print("IP Address: ");
    Serial.println(WiFi.localIP());
    
    // MUST initialize UDP socket!
    udp.begin(udpPort);

    UART_init();
    spiBegin(PIN_IRQ, PIN_RST);
    spiSelect(PIN_SS);
    delay(2);

    uint32_t dev_id = dwt_readdevid();
    Serial.print("BU03 Device ID: 0x");
    Serial.println(dev_id, HEX);

    while (!dwt_checkidlerc()) {
        Serial.println("IDLE FAILED, retrying...");
        delay(10);
    }
    if (dwt_initialise(DWT_DW_INIT) == DWT_ERROR) {
        Serial.println("INIT FAILED"); while(1);
    }
    dwt_setleds(DWT_LEDS_ENABLE | DWT_LEDS_INIT_BLINK);
    if (dwt_configure(&config)) {
        Serial.println("CONFIG FAILED"); while(1);
    }
    dwt_configuretxrf(&txconfig_options);
    dwt_setrxantennadelay(RX_ANT_DLY);
    dwt_settxantennadelay(TX_ANT_DLY);
    dwt_setrxaftertxdelay(POLL_TX_TO_RESP_RX_DLY_UUS);
    dwt_setrxtimeout(RESP_RX_TIMEOUT_UUS);
    dwt_setlnapamode(DWT_LNA_ENABLE);   // PA removed, LNA only

    Serial.println("=====================================");
    Serial.println("  ANCHOR 1 READY (UDP CLIENT)");
    Serial.println("=====================================");
}

void loop() {
    tx_poll_msg[ALL_MSG_SN_IDX] = frame_seq_nb;
    dwt_write32bitreg(SYS_STATUS_ID, SYS_STATUS_TXFRS_BIT_MASK);
    dwt_writetxdata(sizeof(tx_poll_msg), tx_poll_msg, 0);
    dwt_writetxfctrl(sizeof(tx_poll_msg), 0, 1);
    dwt_starttx(DWT_START_TX_IMMEDIATE | DWT_RESPONSE_EXPECTED);

    while (!((status_reg = dwt_read32bitreg(SYS_STATUS_ID)) &
             (SYS_STATUS_RXFCG_BIT_MASK | SYS_STATUS_ALL_RX_TO | SYS_STATUS_ALL_RX_ERR)));

    frame_seq_nb++;

    if (status_reg & SYS_STATUS_RXFCG_BIT_MASK) {
        uint32_t frame_len;
        dwt_write32bitreg(SYS_STATUS_ID, SYS_STATUS_RXFCG_BIT_MASK);

        frame_len = dwt_read32bitreg(RX_FINFO_ID) & RXFLEN_MASK;
        if (frame_len <= sizeof(rx_buffer)) {
            dwt_readrxdata(rx_buffer, frame_len, 0);
            rx_buffer[ALL_MSG_SN_IDX] = 0;

            if (memcmp(rx_buffer, rx_resp_msg, ALL_MSG_COMMON_LEN) == 0) {
                uint32_t poll_tx_ts, resp_rx_ts, poll_rx_ts, resp_tx_ts;
                int32_t rtd_init, rtd_resp;
                float clockOffsetRatio;

                poll_tx_ts = dwt_readtxtimestamplo32();
                resp_rx_ts = dwt_readrxtimestamplo32();
                clockOffsetRatio = ((float)dwt_readclockoffset()) / (uint32_t)(1 << 26);

                resp_msg_get_ts(&rx_buffer[RESP_MSG_POLL_RX_TS_IDX], &poll_rx_ts);
                resp_msg_get_ts(&rx_buffer[RESP_MSG_RESP_TX_TS_IDX], &resp_tx_ts);

                rtd_init = resp_rx_ts - poll_tx_ts;
                rtd_resp = resp_tx_ts - poll_rx_ts;
                double tof = ((rtd_init - rtd_resp * (1.0 - clockOffsetRatio)) / 2.0) * DWT_TIME_UNITS;
                distance = tof * SPEED_OF_LIGHT;

                double filtered = applyFilter(distance);

                if (filtered >= 0) {
                    // Send to STM32 Hub via UDP
                    if (WiFi.status() == WL_CONNECTED) {
                        udp.beginPacket(WiFi.gatewayIP(), udpPort);
                        char msg[32];
                        sprintf(msg, "ANCHOR1: %.2f", filtered);
                        udp.print(msg);
                        udp.endPacket();
                    }
                    
                    Serial.print("ANCHOR 1 DIST: ");
                    Serial.print(filtered, 2);
                    Serial.println(" m");
                }
            }
        }
    } else {
        dwt_write32bitreg(SYS_STATUS_ID, SYS_STATUS_ALL_RX_TO | SYS_STATUS_ALL_RX_ERR);
    }

    // Add slight random jitter to prevent continuous collisions with Anchor 2 and Hub
    delay(RNG_DELAY_MS + random(0, 100));
}

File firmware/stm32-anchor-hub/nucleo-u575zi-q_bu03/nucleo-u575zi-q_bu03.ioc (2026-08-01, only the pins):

Mcu.UserName=STM32U575ZITxQ
PA10.Signal=USART1_RX
PA4.GPIO_Label=UWB_CS
PA4.Signal=GPIO_Output
PA5.Signal=SPI1_SCK
PA6.Signal=SPI1_MISO
PA7.Signal=SPI1_MOSI
PA9.Signal=USART1_TX
PB13.Signal=SPI2_SCK
PB14.Signal=SPI2_MISO
PB15.Signal=SPI2_MOSI
PB2.GPIO_Label=UWB_RST
PB2.Signal=GPIO_Output
PC13.Signal=GPIO_Input
PD14.GPIO_Label=SPI_CS
PD14.Signal=GPIO_Output
PE11.GPIO_Label=CHIP_EN
PE11.Signal=GPIO_Output
PE13.GPIO_Label=SPI_RDY
PE13.Signal=GPXTI13
PE9.GPIO_Label=BOOT
PE9.Signal=GPIO_Output
PF11.GPIO_Label=UWB_WAKE
PF11.Signal=GPIO_Output
PF12.GPIO_Label=UWB_IRQ
PF12.Signal=GPXTI12

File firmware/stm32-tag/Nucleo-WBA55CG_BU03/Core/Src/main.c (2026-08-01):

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
/* Includes ------------------------------------------------------------------*/
#include "main.h"
#include "spi.h"
#include "gpio.h"


COM_InitTypeDef BspCOMInit;

void SystemClock_Config(void);
/* USER CODE BEGIN 0 */
#include <stdio.h>
#include <string.h>
#include "port.h"
#include "deca_device_api.h"
#include "dw3000_deca_regs.h"

#define TX_ANT_DLY 16385
#define RX_ANT_DLY 16385
#define ALL_MSG_SN_IDX 2
#define ALL_MSG_COMMON_LEN 10
#define RESP_MSG_POLL_RX_TS_IDX 10
#define RESP_MSG_RESP_TX_TS_IDX 14
#define POLL_RX_TO_RESP_TX_DLY_UUS 900 // Tag responds 900us after poll
#define UUS_TO_DWT_TIME 65536 // 1 uus = 65536 DWT time units

static dwt_config_t config = {
    5,               /* Channel number. */
    DWT_PLEN_128,    /* Preamble length. Used in TX only. */
    DWT_PAC8,        /* Preamble acquisition chunk size. Used in RX only. */
    9,               /* TX preamble code. Used in TX only. */
    9,               /* RX preamble code. Used in RX only. */
    1,               /* 0 to use standard 8 symbol SFD, 1 to use non-standard 8 symbol, 2 for non-standard 16 symbol SFD and 3 for 4z 8 symbol SDF type */
    DWT_BR_6M8,      /* Data rate. */
    DWT_PHRMODE_STD, /* PHY header mode. */
    DWT_PHRRATE_STD, /* PHY header rate. */
    (129 + 8 - 8),   /* SFD timeout (preamble length + 1 + SFD length - PAC size). Used in RX only. */
    DWT_STS_MODE_OFF,
    DWT_STS_LEN_64,  /* STS length, see allowed values in Enum dwt_sts_lengths_e */
    DWT_PDOA_M0      /* PDOA mode off */
};
static dwt_txconfig_t txconfig_options = {
    0x34,           /* PG delay. */
    0xfdfdfdfd,      /* TX power. */
    0x0             /* PG count. */
};

static uint8_t rx_buffer[20];
static uint8_t tx_resp_msg[] = {0x41, 0x88, 0, 0xCA, 0xDE, 'V', 'E', 'W', '0', 0xE1, 0, 0, 0, 0, 0, 0, 0, 0, 0, 0};
static uint8_t frame_seq_nb = 0;
static uint64_t poll_rx_ts;
static uint64_t resp_tx_ts;

static uint64_t get_rx_timestamp_u64(void)
{
    uint8_t ts_tab[5];
    uint64_t ts = 0;
    int i;
    dwt_readrxtimestamp(ts_tab, 0);
    for (i = 4; i >= 0; i--) {
        ts <<= 8;
        ts |= ts_tab[i];
    }
    return ts;
}

static void resp_msg_set_ts(uint8_t *ts_field, const uint64_t ts)
{
    int i;
    for (i = 0; i < 4; i++) {
        ts_field[i] = (uint8_t)(ts >> (i * 8));
    }
}
/* USER CODE END 0 */

/**
  * @brief  The application entry point.
  * @retval int
  */
int main(void)
{

  /* MCU Configuration--------------------------------------------------------*/

  /* Reset of all peripherals, Initializes the Flash interface and the Systick. */
  HAL_Init();

  /* Configure the system clock */
  SystemClock_Config();

  /* Initialize all configured peripherals */
  MX_GPIO_Init();
  MX_SPI1_Init();
  /* USER CODE BEGIN 2 */
  
  /* Initialize COM1 port */
  BspCOMInit.BaudRate   = 115200;
  BspCOMInit.WordLength = COM_WORDLENGTH_8B;
  BspCOMInit.StopBits   = COM_STOPBITS_1;
  BspCOMInit.Parity     = COM_PARITY_NONE;
  BspCOMInit.HwFlowCtl  = COM_HWCONTROL_NONE;
  if (BSP_COM_Init(COM1, &BspCOMInit) != BSP_ERROR_NONE)
  {
    Error_Handler();
  }
  
  printf("\r\n==================================\r\n");
  printf("STM32 Baremetal UWB TAG Started\r\n");
  printf("==================================\r\n");

  extern SPI_HandleTypeDef hspi1;
  extern SPI_HandleTypeDef *hcurrent_active_spi;
  extern uint16_t          pin_io_active_spi;
  
  hcurrent_active_spi = &hspi1;
  pin_io_active_spi = UWB_CS_Pin;

  reset_DWIC();      // Toggle RST pin

  // Simple Device ID check to verify SPI
  uint8_t tx_cmd[1] = {0x00}; 
  uint8_t rx_buf[4] = {0, 0, 0, 0};
  HAL_GPIO_WritePin(UWB_CS_GPIO_Port, UWB_CS_Pin, GPIO_PIN_RESET);
  HAL_SPI_Transmit(&hspi1, tx_cmd, 1, HAL_MAX_DELAY);
  HAL_SPI_Receive(&hspi1, rx_buf, 4, HAL_MAX_DELAY);
  HAL_GPIO_WritePin(UWB_CS_GPIO_Port, UWB_CS_Pin, GPIO_PIN_SET);
  uint32_t dev_id = (rx_buf[3] << 24) | (rx_buf[2] << 16) | (rx_buf[1] << 8) | rx_buf[0];
  printf("BU03 Device ID test: 0x%08lX\r\n", dev_id);

  extern const struct dwt_probe_s dw3000_probe_interf;
  if (dwt_probe((struct dwt_probe_s *)&dw3000_probe_interf) != DWT_SUCCESS) {
      printf("dwt_probe failed!\r\n");
      while (1) {};
  }

  while (!dwt_checkidlerc()) {
      printf("IDLE FAILED, retrying...\r\n");
      HAL_Delay(10);
  }
  
  if (dwt_initialise(DWT_DW_INIT) == DWT_ERROR) {
      printf("INIT FAILED\r\n");
      while (1);
  }
  
  dwt_setleds(DWT_LEDS_ENABLE | DWT_LEDS_INIT_BLINK);
  
  if (dwt_configure(&config)) {
      printf("CONFIG FAILED\r\n");
      while (1);
  }
  
  dwt_configuretxrf(&txconfig_options);
  dwt_setrxantennadelay(RX_ANT_DLY);
  dwt_settxantennadelay(TX_ANT_DLY);
  dwt_setlnapamode(DWT_LNA_ENABLE);

  printf("Tag (STM32) Ready! Listening for polls...\r\n");

  // Enable RX for the first time
  dwt_rxenable(DWT_START_RX_IMMEDIATE);

  /* USER CODE END 2 */

  /* Infinite loop */
  /* USER CODE BEGIN WHILE */
  while (1)
  {
    uint32_t status_reg;
    while (!((status_reg = dwt_read_reg(SYS_STATUS_ID)) &
             (SYS_STATUS_RXFCG_BIT_MASK | SYS_STATUS_ALL_RX_TO | SYS_STATUS_ALL_RX_ERR))) {
                 // Wait for packet
             }

    if (status_reg & SYS_STATUS_RXFCG_BIT_MASK) {
        dwt_write_reg(SYS_STATUS_ID, SYS_STATUS_RXFCG_BIT_MASK); // Clear flag

        uint32_t frame_len = dwt_read_reg(RX_FINFO_ID) & RX_FINFO_RXFLEN_BIT_MASK;
        if (frame_len <= sizeof(rx_buffer)) {
            dwt_readrxdata(rx_buffer, frame_len, 0);

            // Check if it's a Poll message (0xE0)
            if (rx_buffer[9] == 0xE0) { 
                uint32_t resp_tx_time;

                poll_rx_ts = get_rx_timestamp_u64();
                
                resp_tx_time = (poll_rx_ts + ((uint64_t)POLL_RX_TO_RESP_TX_DLY_UUS * UUS_TO_DWT_TIME)) >> 8;
                dwt_setdelayedtrxtime(resp_tx_time);
                
                resp_tx_ts = (((uint64_t)(resp_tx_time & 0xFFFFFFFEUL)) << 8) + TX_ANT_DLY;

                resp_msg_set_ts(&tx_resp_msg[RESP_MSG_POLL_RX_TS_IDX], poll_rx_ts);
                resp_msg_set_ts(&tx_resp_msg[RESP_MSG_RESP_TX_TS_IDX], resp_tx_ts);

                // Echo back anchor ID byte ('1','2','3') and sequence number
                tx_resp_msg[8] = rx_buffer[8]; 
                tx_resp_msg[ALL_MSG_SN_IDX] = frame_seq_nb;

                dwt_writetxdata(sizeof(tx_resp_msg), tx_resp_msg, 0);
                dwt_writetxfctrl(sizeof(tx_resp_msg), 0, 1);
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

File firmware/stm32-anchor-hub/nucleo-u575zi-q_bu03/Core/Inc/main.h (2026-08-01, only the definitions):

#define UWB_CS_Pin GPIO_PIN_4
#define UWB_CS_GPIO_Port GPIOA
#define UWB_RST_Pin GPIO_PIN_2
#define UWB_RST_GPIO_Port GPIOB
#define UWB_WAKE_Pin GPIO_PIN_11
#define UWB_WAKE_GPIO_Port GPIOF
#define UWB_IRQ_Pin GPIO_PIN_12
#define UWB_IRQ_GPIO_Port GPIOF
#define UWB_IRQ_EXTI_IRQn EXTI12_IRQn
#define BOOT_Pin GPIO_PIN_9
#define BOOT_GPIO_Port GPIOE
#define CHIP_EN_Pin GPIO_PIN_11
#define CHIP_EN_GPIO_Port GPIOE
#define SPI_RDY_Pin GPIO_PIN_13
#define SPI_RDY_GPIO_Port GPIOE
#define SPI_RDY_EXTI_IRQn EXTI13_IRQn
#define SPI_CS_Pin GPIO_PIN_14
#define SPI_CS_GPIO_Port GPIOD

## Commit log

2026-08-06 Added proper kicad project export
2026-08-06 BOM added

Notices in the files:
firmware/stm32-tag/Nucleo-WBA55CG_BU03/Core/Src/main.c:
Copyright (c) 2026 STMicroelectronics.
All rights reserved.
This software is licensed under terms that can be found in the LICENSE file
